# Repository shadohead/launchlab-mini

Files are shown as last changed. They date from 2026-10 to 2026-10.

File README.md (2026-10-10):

# LaunchLab Mini for Beyblade X

**A removable launch-practice meter for Beyblade X string launchers.** LaunchLab Mini uses an optical sensor to measure the launcher's shaft speed, then shows your peak RPM, launch history, and a replay of the device's tilt and rotation on an M5StickS3 screen. Use it to compare pulls, track consistency across practice sessions, and try to repeat a chosen launch.

Built around **M5StickS3 K150**, with separate printed mounts for the **small analog QRE1113** or **older TCRT5000 / LM393** sensor. The current firmware supports both sensors through a saved Sensor profile setting; the old TCRT 0.2.0 build is preserved separately. The M5 keeps its factory case, display, controller and battery; you do not need a phone to view your results. The mount is designed to be removable. Check the supplied launcher interface and printed fit before using it on your launcher.

**[USB firmware updater](https://shadohead.github.io/launchlab-mini/) · [Recovery & M5Stack reinstall](docs/RECOVERY.md) · [Firmware & print releases](https://github.com/shadohead/launchlab-mini/releases) · [Parts list & Amazon links](#parts-list--build-your-own) · [Build & wiring](docs/BUILD.md)**

**Prototype validation:** **0.11.1** is the user-checked prototype revision. It adds saved themes (Classic, Mint, Amber, Violet), a personal-best effect on the recap, and USB backup and restore of history, personal bests, appearance and settings (`K` export, `R` restore). It fixes 0.11.0, which restarted about once a second after boot (a loop-task stack overflow) and was withdrawn. One firmware still serves both sensors through the saved **Sensor profile** setting (QRE / Standard with an 80-count mark floor, TCRT5000 with 60). It was installed app-only on the owner's M5StickS3 K150: no restarts in a 120 s soak, history kept, a backup and restore round trip identical, and the screen, themes and pulls confirmed. The detector, sampling, thresholds and saved history format are unchanged from 0.10.22, which keeps measuring pulls that start right after an automatic save. Battery endurance, long-session reliability, absolute RPM/angle calibration, physical browser transfer and first install/rollback, and stock recovery remain separate checks.

## Sidecar form factor

**Sidecar** is the LaunchLab form factor with the M5StickS3 mounted on its own carrier beside a separate optical sensor attachment. Sidecar supports either QRE1113 or TCRT5000; the name describes the mounting layout, not the sensor, firmware or hardware revision.

See the [Sidecar build guide](docs/BUILD.md) and [hardware downloads](docs/HARDWARE_VERSIONS.md#current-downloads).

## Parts list — build your own

Start with **one M5StickS3 K150 + one analog sensor + three short wires + printed mounts and M2 screws**. The StickS3 already contains the display, processor, IMU and battery. Choose **QRE1113** for the current firmware/UI, or **TCRT5000 / LM393** for the preserved old-sensor firmware.

**Amazon affiliate disclosure:** As an Amazon Associate I earn from qualifying purchases. Amazon links below use the [Beywatch](https://beywatch.gg/) affiliate tag and help support the project at no extra cost to you.

| Qty per build | Part | Which build / purchase notes | Buy |
| --- | --- | --- | --- |
| 1 | **M5StickS3 K150** | Both sensor builds. ESP32-S3, 8 MB flash/PSRAM, intact factory case. | [Amazon — M5Stack Official, ordered](https://www.amazon.com/dp/B0GWHN8HK3?tag=beywatchgg-20) · [M5Stack K150 specs](https://docs.m5stack.com/en/core/StickS3) |
| 1 | **SparkFun QRE1113 analog breakout, ROB-09453** | Small-sensor build; exact ordered listing. **Analog ROB-09453** is required. Use the SparkFun link if Amazon is unavailable. | [Amazon — SparkFun analog board](https://www.amazon.com/dp/B07YM4551X?tag=beywatchgg-20) · [SparkFun](https://www.sparkfun.com/sparkfun-line-sensor-breakout-qre1113-analog.html) |
| 1, instead of QRE | **TCRT5000 / LM393 module with AO** | Old-sensor build. Choose the four-pin **VCC/GND/D0/A0** module and use A0. The mount uses the measured 31×13×1 mm PCB; check your board/header dimensions. | [Amazon — HiLetgo 10-pack, ordered](https://www.amazon.com/dp/B00LZV1V10?tag=beywatchgg-20) |
| 3 leads | **Short 2.54 mm jumper wires** | VCC, GND and AO/OUT; the ordered SinLoon pack is 8 cm male-to-female. Trim/reroute as needed, checking connector clearance. | [Amazon — SinLoon 8 cm](https://www.amazon.com/dp/B08M3QLL3Q?tag=beywatchgg-20) · [Amazon — ELEGOO mixed jumper kit](https://www.amazon.com/dp/B01EV70C78?tag=beywatchgg-20) |
| 1 | **USB-C data cable** | Flashing and charging; use an existing cable that carries data. | Use an existing data cable, or [Amazon search — USB-C data cable](https://www.amazon.com/s?k=USB-C+data+cable&tag=beywatchgg-20) |
| 1 set | **Printed M5 + sensor mounts** | QRE: six-piece v0.40 plate. TCRT: six v0.43 sensor pieces + a separate M5 carrier. v0.68 M5 with wire channel and shortened hook is the preferred separate carrier. | [Print files](docs/HARDWARE_VERSIONS.md#current-downloads) |
| See below | **M2 machine screws** | Head style and length depend on the mount revision. | [Amazon — ordered MEIYYJ countersunk assortment](https://www.amazon.com/dp/B07HC3LQYS?tag=beywatchgg-20); pan-head sizes below |
| Small amount | **1.75 mm PLA filament** | Print yourself or use a printing service; saved profiles target P1S / 0.4 mm nozzle. | Use existing PLA, a printing service, or [Amazon search — PLA filament](https://www.amazon.com/s?k=1.75mm+PLA+filament&tag=beywatchgg-20) |

Links marked **ordered**, plus the SparkFun, SinLoon, ELEGOO and uxcell links, match the project-related product listings from purchase history. Cable, filament and pan-head links marked **Amazon search** are general supplies, not exact ordered products. Check the selected variant and pack contents; purchasing a component does not establish printed fit.

### Screws, connectors and tools

The ordered MEIYYJ assortment includes M2×4/5/6/8 **flat/countersunk heads**. Its M2×5 pieces can supply the clip/crossbar screws, subject to head-seat fit. Obtain the **pan-head** pieces separately: [Amazon search — M2×4 pan-head](https://www.amazon.com/s?k=M2x4+pan+head+machine+screws&tag=beywatchgg-20) · [Amazon search — M2×6 pan-head](https://www.amazon.com/s?k=M2x6+pan+head+machine+screws&tag=beywatchgg-20).

| Assembly | Screws required |
| --- | --- |
| Original v0.40 M5 carrier | 2 × **M2×6 pan-head**, from below into the StickS3 mounts. |
| QRE v0.40 plate sensor assembly | 2 × **M2×5 countersunk** for the latch crossbar + 2 × **M2×4 pan-head** for the sensor pressure plate. |
| TCRT v0.43 sensor assembly | 2 × **M2×5 countersunk** for the separate clip caps + 2 × **M2×4 pan-head** for the sensor keeper; M5 fasteners are additional. |
| Preferred v0.68 M5 carrier | 2 × M2 screws; M2×6 is the nominal reference. **Actual length, insert engagement and seating remain unverified.** |

If your sensor has bare pads, add a **3-pin 2.54 mm header** or solder the three wires directly. The ordered [uxcell right-angle male header strip](https://www.amazon.com/dp/B01461DQ6S?tag=beywatchgg-20) can be cut to three pins; check header direction and cable clearance against the printed seat. You will also need a small screwdriver, cutters, and a soldering iron/solder if attaching bare wires or headers.

Use a **Beyblade X string launcher with the supplied removable clip/port interface**. The interface derives from Migbello's BP Gear Port Connector; check retention and optical access on your actual launcher before a pull. No universal launcher-fit claim is made by these CAD files.

Wire **AO/OUT → G1 / GPIO1**, **VCC → 3V3 / 3V3_L2**, **GND → GND**. DO is unused. The Grove red lead supplies 5 V; use the Hat 3.3 V pin for these builds. [QRE build/wiring](docs/BUILD.md) · [TCRT build/wiring](docs/TCRT5000.md) · [Sensor and hardware versions](docs/HARDWARE_VERSIONS.md).

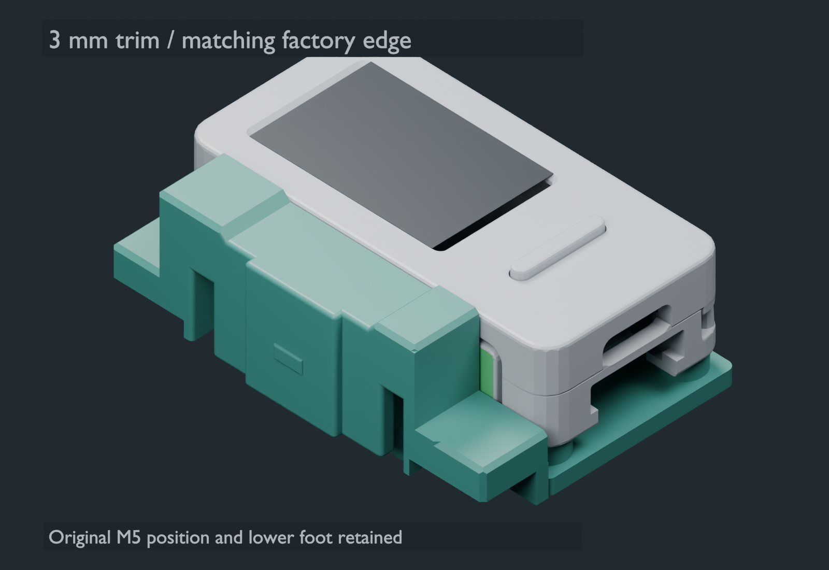
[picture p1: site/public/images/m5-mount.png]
LaunchLab Mini M5StickS3 mount, rendered from the published CAD


The updater defaults to **0.11.2**. It checks the complete known installed application before an app-only update, blocks downgrades and unknown/incomplete images, and skips writing an identical version. **Repair / rollback** requires an explicit target/backup confirmation; both app-only paths require the matching partition layout and boot selection. All modes check the detected ESP32-S3 chip and 8 MB flash capacity. The previous 0.11.1, 0.10.22, 0.10.21, 0.10.14, 0.10.11, 0.10.7 and 0.10.1 binaries are preserved. Physical browser transfer, four-image installation of this revision, stock recovery and rollback remain unverified. [Update details](docs/UPDATER.md) · [Recovery and vendor reinstall](docs/RECOVERY.md).

Current firmware: **0.11.2** (QRE1113 or TCRT5000 via Sensor profile). Old TCRT firmware: **0.2.0**. Preferred separate M5 carrier: **v0.68**; latest TCRT mount: **v0.43**. The original QRE **v0.40** complete plate is still available. Firmware, M5 carrier and sensor-mount versions are independent.

**[Choose your sensor and see every revision](docs/HARDWARE_VERSIONS.md)** — includes the preferred v0.68 M5 carrier, earlier v0.41–v0.50 models, historical v0.19 TCRT, and current QRE files.

## What it does

The current revision is **0.11.2**, running at 80 MHz with unchanged 50 kS/s optical sampling. It adds saved themes, a personal-best recap effect and USB backup/restore (`K`/`R`), and its build fails if any stack frame exceeds its budget. A saved Sensor profile selects QRE / Standard (80-count mark floor) or TCRT5000 (60-count floor). Controls are simpler: A opens or applies, B advances, hold B goes back or cancels. A saved 180-degree display flip and previewed brightness live in Settings. IMU startup recovery, prompt recaps, power diagnostics, tournament mode and USB keep-awake are retained; battery savings remain unmeasured. The old TCRT 0.2.0 release is an earlier RPM acquisition build with its own detector thresholds.

| Feature | What you see or do |
| --- | --- |
| Optical peak RPM | Three-turn elapsed-time average peak by default; validated single-turn peak is selectable in Settings. Three consistent turns confirm the pull before a peak is recorded. |
| Live level | Use the bubble and tilt angle while holding still to check the device's orientation before launching. |
| Launch recap | After a pull, see peak RPM, a clearer Start-to-End rotation replay, and frozen Start/End tilt circles. Press A to recall the latest recap. |
| Launch history | Review recent pulls and the current session's pull count, average, and best RPM. Retains up to 128 launches and 24 sessions on the device. |
| Pull and session trends | Compare individual pulls, a trailing five-pull average, and session averages to follow your practice consistency. |
| Tournament mode | Hold A on main to enter or exit; B cycles Recording Only/RPM. |
| Battery and auto-off | Check percentage, voltage and charging status. Shake-to-wake sleep after a configurable 1–10 minutes (3-minute default) without activity; a detected USB computer keeps it awake. |
| Browser firmware updates | Install over USB in desktop Chrome or Edge. Updates write only the application after checking the partition layout. |

RPM is **launcher-shaft speed**, not a direct measurement of the Beyblade's release RPM or its spin in the stadium. Motion replay shows rotation and gravity-relative tilt; it does not measure travel distance or absolute compass heading. The live level references the screen plane until the mounting orientation is calibrated.

## Device UI

These are saved device-framebuffer screenshots, not concept UI. Screens marked **DEMO** use synthetic sample data. The live/recap images are from firmware 0.6.2, and are historical examples; 0.10.1 has a revised tilt recap; history/trend images are from the 0.3.0 baseline and battery from 0.3.1. [Image provenance](docs/assets/ui/provenance.json) records their sources.

<table>
<tr><th>Live RPM & level</th><th>Launch recap</th><th>Launch history</th></tr>
<tr>
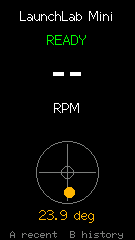
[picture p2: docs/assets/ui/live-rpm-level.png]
Idle live screen showing READY, RPM placeholder and bubble level
<td align="center"></td>
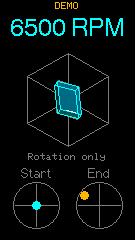
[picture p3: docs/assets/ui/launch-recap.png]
Demo launch recap showing 6500 RPM, a rotation replay and frozen start/end tilt circles
<td align="center"></td>
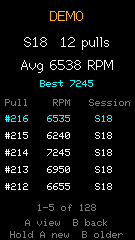
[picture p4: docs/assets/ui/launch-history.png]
Demo launch history listing pull RPM with session count, mean and best
<td align="center"></td>
</tr>
<tr><td>Ready state, held RPM result and level.</td><td>Recall the latest pull with A.</td><td>Browse pulls and session summaries.</td></tr>
</table>

<table>
<tr><th>Pull trend</th><th>Session trend</th><th>Battery</th></tr>
<tr>
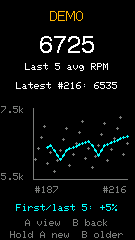
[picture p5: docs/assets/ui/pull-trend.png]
Demo pull trend with individual measurements and a five-pull average
<td align="center"></td>
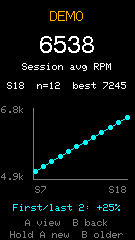
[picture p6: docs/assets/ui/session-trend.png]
Demo session trend plotting session-average RPM
<td align="center"></td>
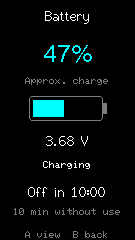
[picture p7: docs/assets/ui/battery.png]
Battery page showing approximate charge, voltage, charging state and auto-off countdown
<td align="center"></td>
</tr>
<tr><td>See variation across recent pulls.</td><td>Compare averages across sessions.</td><td>Check power before practice.</td></tr>
</table>

From the live screen, **A shows the last recap** and **B opens the menu** (History, New session, Battery, Settings, Tournament). In menus, A opens or applies, B moves to the next choice and hold B goes back one level or cancels an edit. Settings holds Sleep after, RPM method, Brightness, Flip display and Sensor profile; brightness and flip preview before you apply them. Hold A on main for one second to enter tournament mode (B cycles Recording Only/RPM; hold A exits). See the [firmware guide](firmware/LaunchLabMini/README.md).

## Exploded assemblies

The **Sidecar form factor** has **two independent assemblies**: the M5 display mount and your chosen optical sensor attachment (QRE1113 or TCRT5000). The views below use the exact published CAD meshes, separated for illustration. They do not assert a measured combined mounting position on a complete launcher. Electronics and screws are reference envelopes, not printed parts.

### Preferred M5StickS3 carrier — v0.68

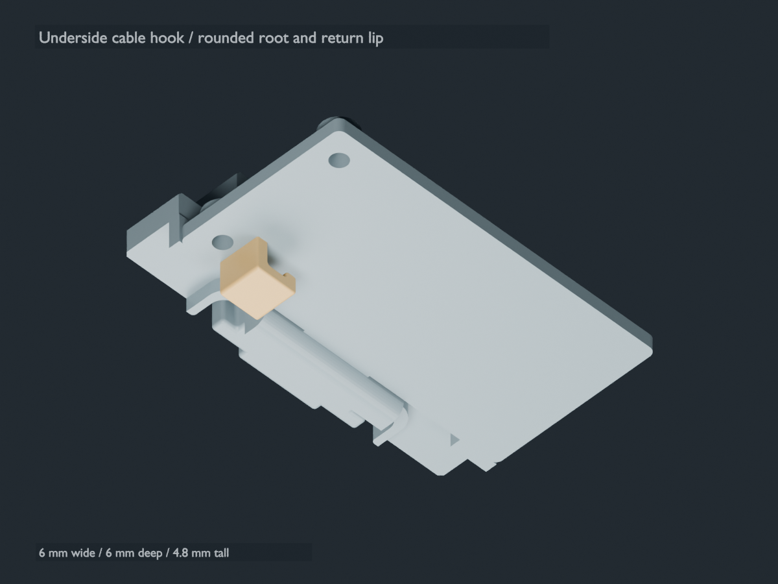
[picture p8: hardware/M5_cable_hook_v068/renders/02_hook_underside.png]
Preferred v0.68 M5 carrier with underside cable hook


One replacement carrier retains the two older support humps and adds the side-open
wire channel plus a **6 mm long, 4.8 mm tall underside hook**, opening downward in
the bottom-face preview. The hook is 2 mm shorter than v0.66. The sensor mount
remains separate. [P1S PLA 3MF](hardware/M5_cable_hook_v068/bambu/LaunchLab_v068_P1S_PLA_M5_ATTACHMENT_PROTOTYPE.3mf)
· [Complete package](hardware/M5_cable_hook_v068_package.zip)
· [STL, editable CAD and rebuild source](hardware/M5_cable_hook_v068/README.md).
Saved slice: **43m33s / 8.38 g PLA**. Physical seating, screw engagement, hook
strength and cable retention remain unverified. Stagger the three leads inside
the smaller hook and keep plug housings outside its opening.

### Earlier M5StickS3 carrier — v0.50

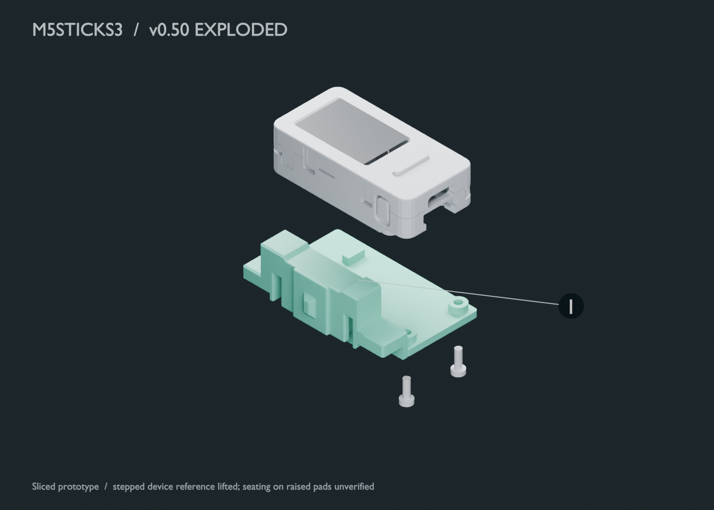
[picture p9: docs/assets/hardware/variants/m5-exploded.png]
Exploded earlier M5 v0.50 carrier, intact device reference and underside screws


**1 — Earlier equal-height M5 carrier:** one replacement printed piece with the v0.49 soft center ramp, recessed screw heads and supports raised to 2.3 mm. [Download v0.50 3MF](hardware/M5_equal_supports_v050/bambu/LaunchLab_v050_P1S_PLA_M5_EQUAL_SUPPORTS_TREE_SLIM.3mf) · [Full package](hardware/M5_equal_supports_v050_package.zip). Saved slice: 43m18s / 9.24 g PLA.

**Prototype: physical seating and leveling are unverified.** The original nominal M5 reference overlaps the taller pads in its saved assembly pose; it is lifted here for illustration. Screw length and insert engagement must be checked after the counterbore revision. STEP files contain only the added supports; the full carrier is mesh geometry.

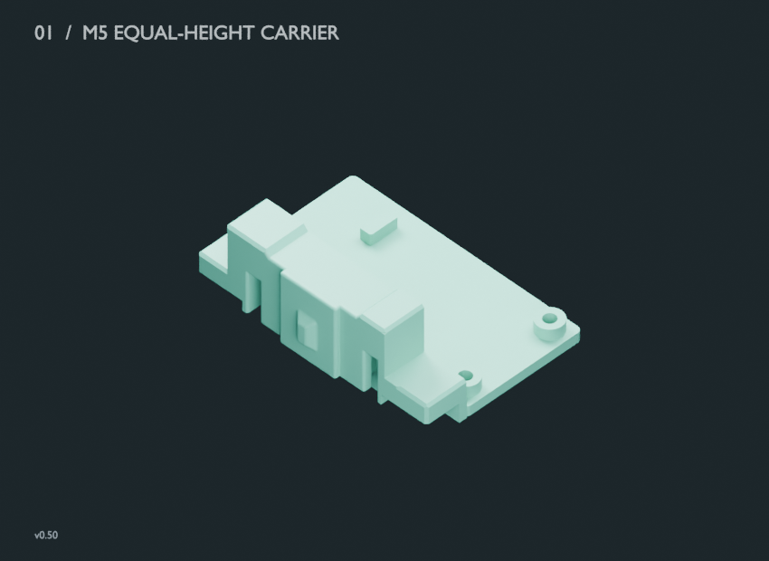
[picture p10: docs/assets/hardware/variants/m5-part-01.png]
Actual v0.50 printed M5 equal-height support carrier


### Earlier M5StickS3 display mount — v0.40

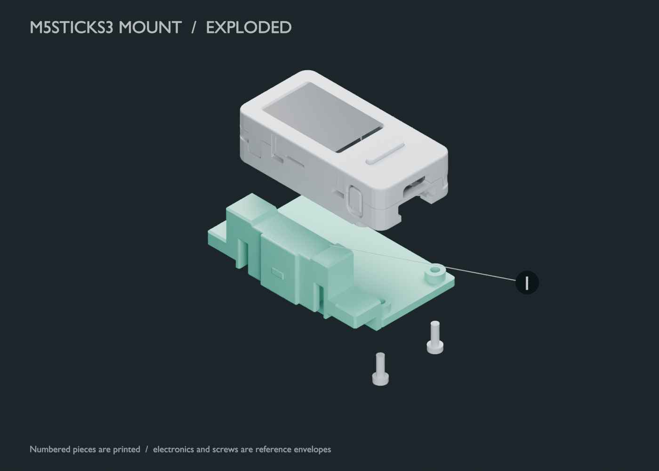
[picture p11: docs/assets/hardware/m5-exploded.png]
Exploded M5StickS3 assembly showing printed part 1, the intact M5StickS3 and underside screws


**1 — M5 platform:** supports the intact M5StickS3. Two M2×6 screws install from underneath into the device's existing mounts. The factory device, screen and soft-liner references are lifted for visibility in this view.

### Small QRE1113 sensor attachment

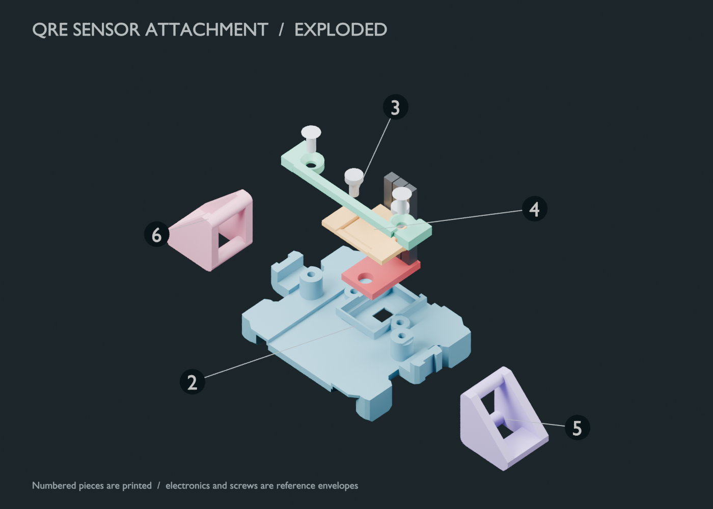
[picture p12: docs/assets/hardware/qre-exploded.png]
Exploded QRE1113 assembly showing the sensor base, latch crossbar, pressure plate, both launcher latches, sensor and fasteners


| No. | Printed piece | Purpose | Fasteners |
| --- | --- | --- | --- |
| 2 | QRE sensor base | Locates the small analog board and retains the launcher-facing interface. | Receives the crossbar and pressure-plate screws. |
| 3 | Latch crossbar | Retains the launcher latch assembly. | 2 × M2×5 countersunk. |
| 4 | Sensor pressure plate | Holds the QRE board against its seat. | 2 × M2×4 pan-head. |
| 5 | Left launcher latch | One side of the removable launcher attachment. | Retained by the base/crossbar assembly. |
| 6 | Right launcher latch | Opposite side of the removable launcher attachment. | Retained by the base/crossbar assembly. |

### Old TCRT5000 sensor attachment — v0.43

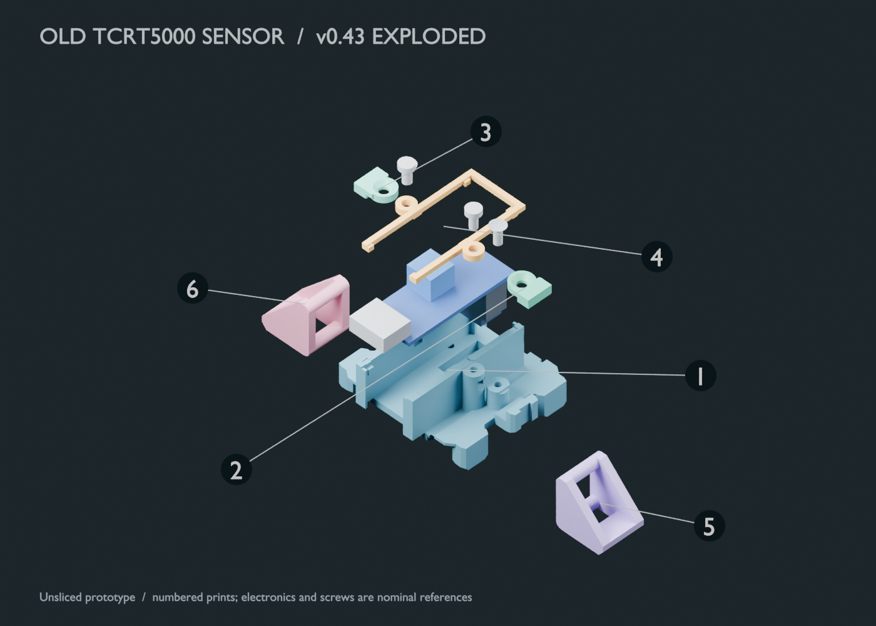
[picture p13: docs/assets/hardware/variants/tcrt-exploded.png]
Exploded TCRT5000 v0.43 mount with six printed pieces, analog sensor and nominal screws


This version uses the **older 31×13×1 mm TCRT5000 / LM393 PCB**. Two independent screw-on clip caps replace the earlier crossbar; M5 stays on a separate carrier. [Six-piece CAD/STL/STEP package](hardware/minimal_TCRT_split_keepers_v043_package.zip) · [Old-sensor wiring & firmware](docs/TCRT5000.md). This is an **unsliced CAD prototype**; fit, solder clearance, preload and optical alignment still need checking.

| No. | Printed piece | Purpose |
| --- | --- | --- |
| 1 | TCRT sensor cradle | Locates the larger board and preserves the launcher interface. |
| 2 | Left clip cap | Retains one launcher latch with an M2×5 countersunk screw. |
| 3 | Right clip cap | Retains the opposite latch with an M2×5 countersunk screw. |
| 4 | Sensor pressure keeper | Holds the board with two M2×4 pan-head screws. |
| 5 | Left launcher latch | Removable launcher attachment. |
| 6 | Right launcher latch | Opposite side of the launcher attachment. |

<table>
<tr><th>1 · TCRT cradle</th><th>2 · Left cap</th><th>3 · Right cap</th></tr>
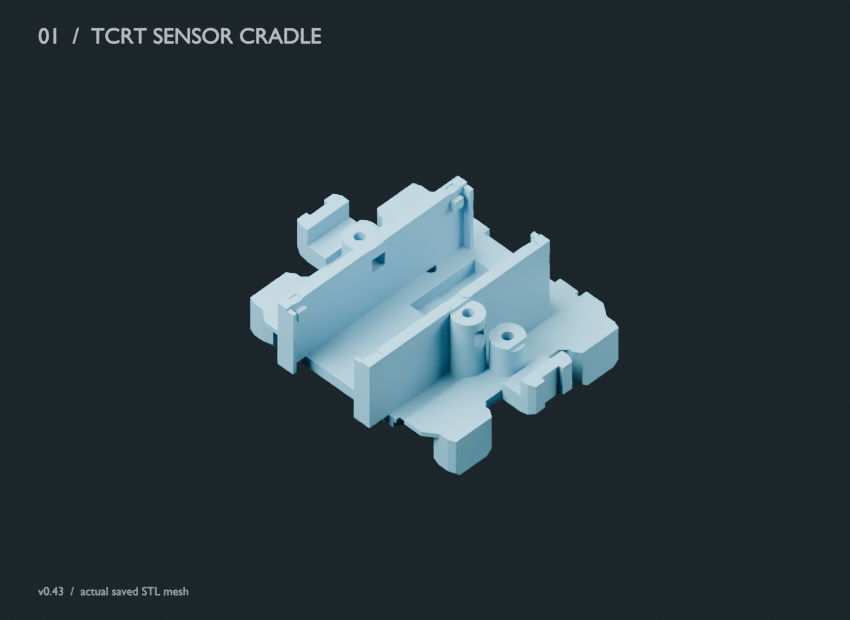
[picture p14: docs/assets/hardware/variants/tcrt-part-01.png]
TCRT sensor cradle
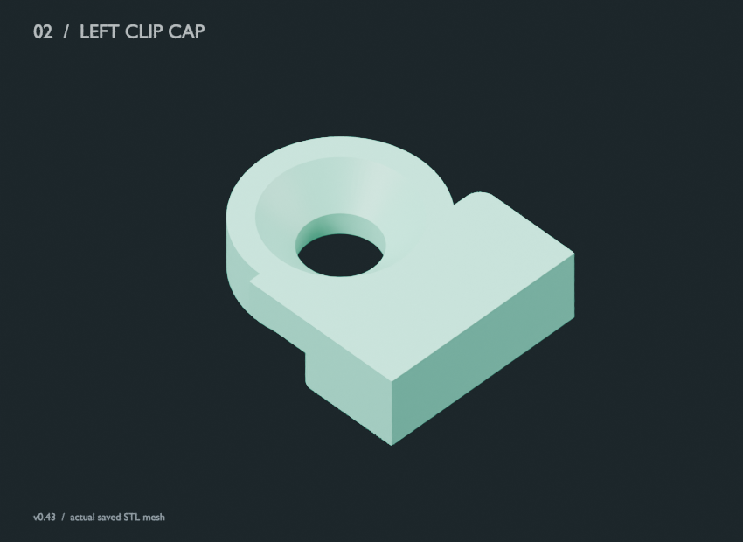
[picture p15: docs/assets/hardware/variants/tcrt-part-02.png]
Left TCRT clip cap
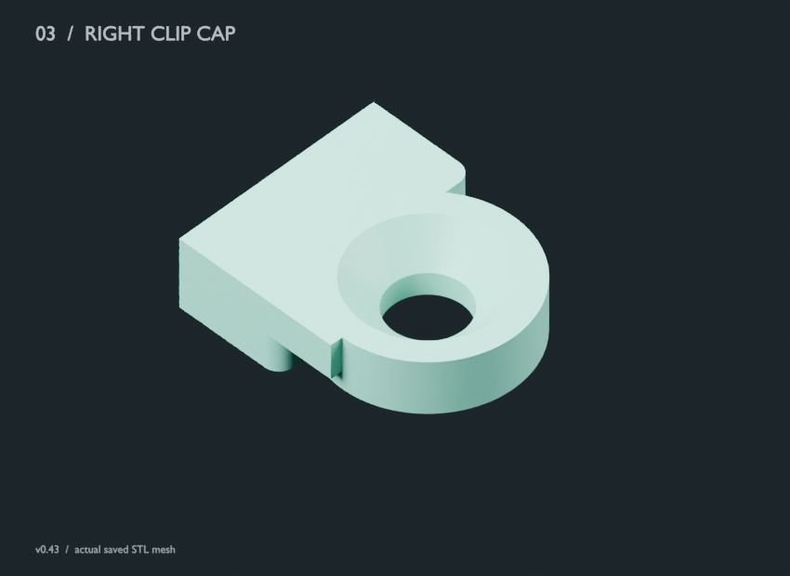
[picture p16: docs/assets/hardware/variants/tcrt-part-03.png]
Right TCRT clip cap
<tr><td></td><td></td><td></td></tr>
<tr><th>4 · Pressure keeper</th><th>5 · Left latch</th><th>6 · Right latch</th></tr>
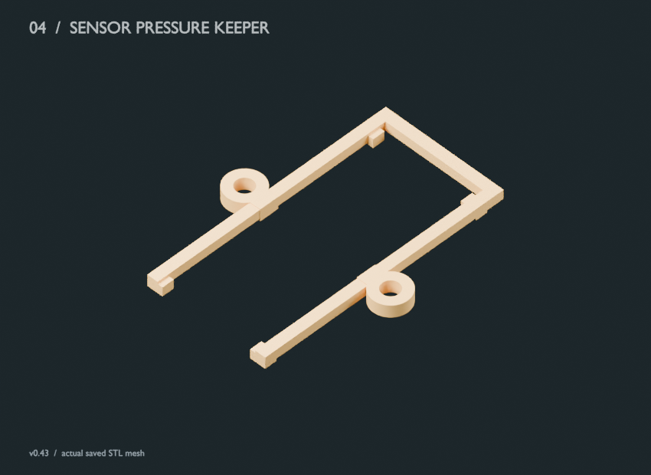
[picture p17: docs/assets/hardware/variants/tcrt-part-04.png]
TCRT pressure keeper
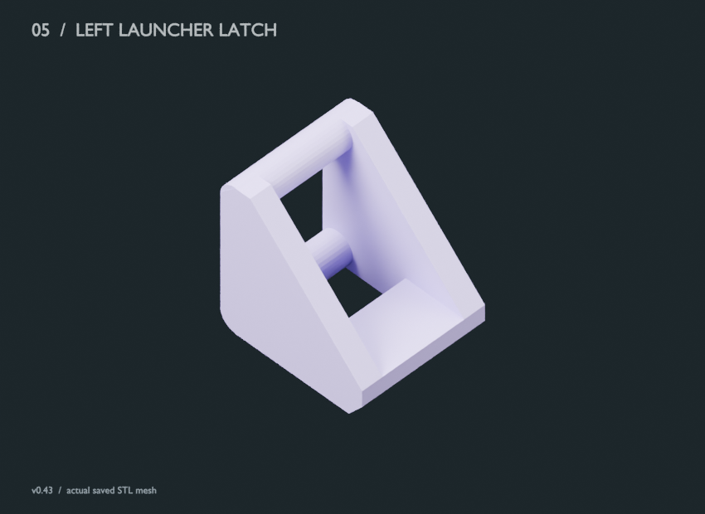
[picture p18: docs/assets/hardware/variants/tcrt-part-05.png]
Left TCRT launcher latch
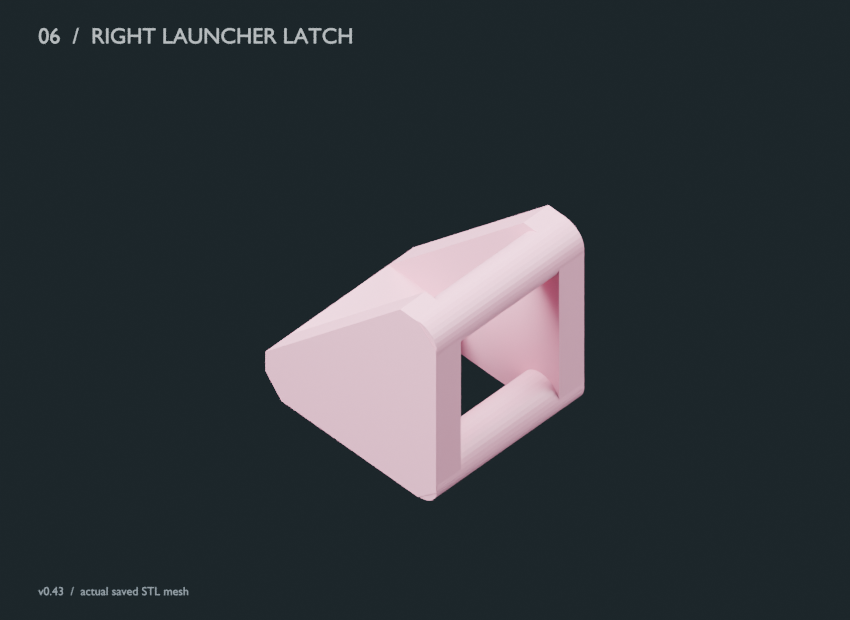
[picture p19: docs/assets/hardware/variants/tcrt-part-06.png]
Right TCRT launcher latch
<tr><td></td><td></td><td></td></tr>
</table>

### Each original QRE printed piece — v0.40 plate

All six pieces are included in the complete v0.40 plate. The views below show their actual mesh geometry; each build uses one of each.

<table>
<tr><th>1 · M5 platform</th><th>2 · QRE sensor base</th><th>3 · Latch crossbar</th></tr>
<tr>
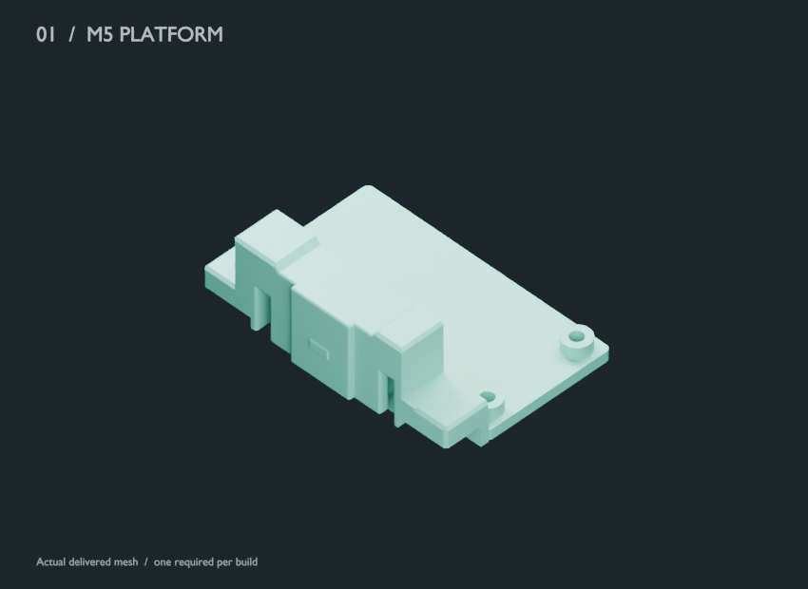
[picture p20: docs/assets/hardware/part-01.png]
Individual M5StickS3 stepped mounting platform
<td></td>
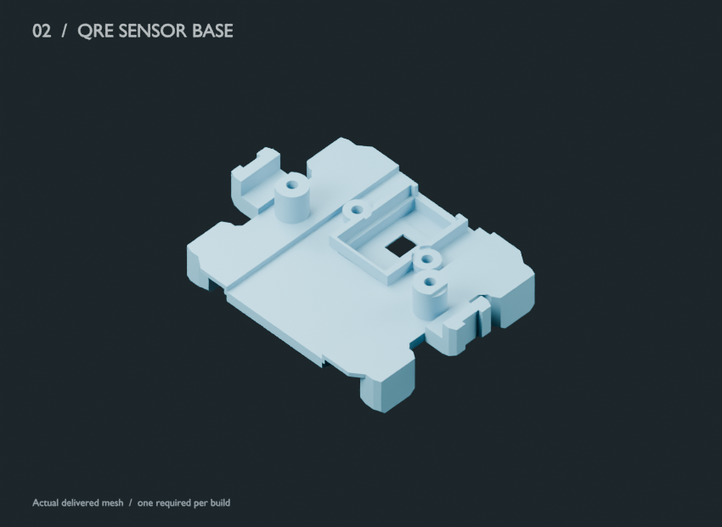
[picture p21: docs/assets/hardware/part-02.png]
Individual QRE1113 sensor base
<td></td>
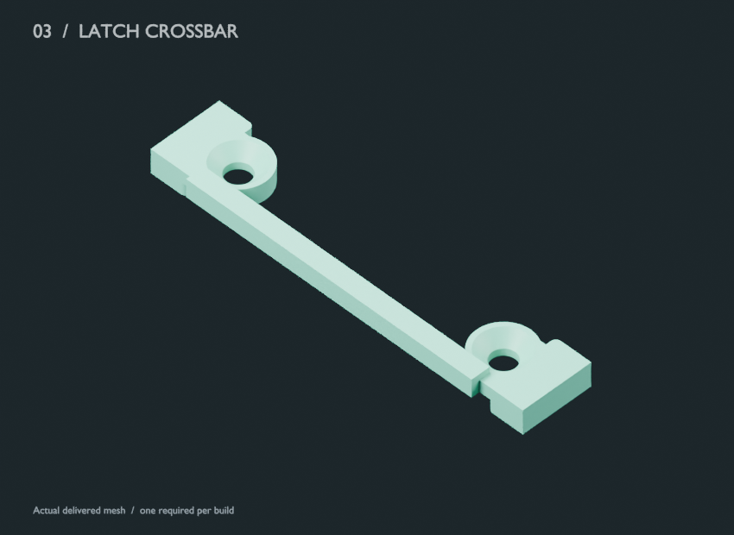
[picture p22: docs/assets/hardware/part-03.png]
Individual printed latch crossbar
<td></td>
</tr>
<tr><th>4 · Pressure plate</th><th>5 · Left launcher latch</th><th>6 · Right launcher latch</th></tr>
<tr>
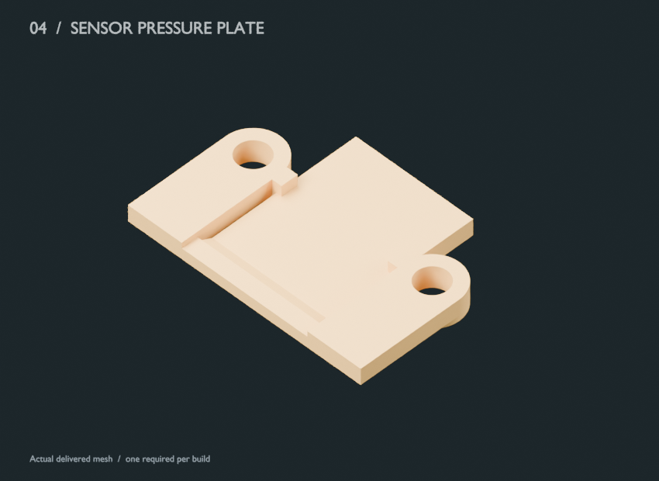
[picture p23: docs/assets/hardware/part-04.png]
Individual QRE1113 sensor pressure plate
<td></td>
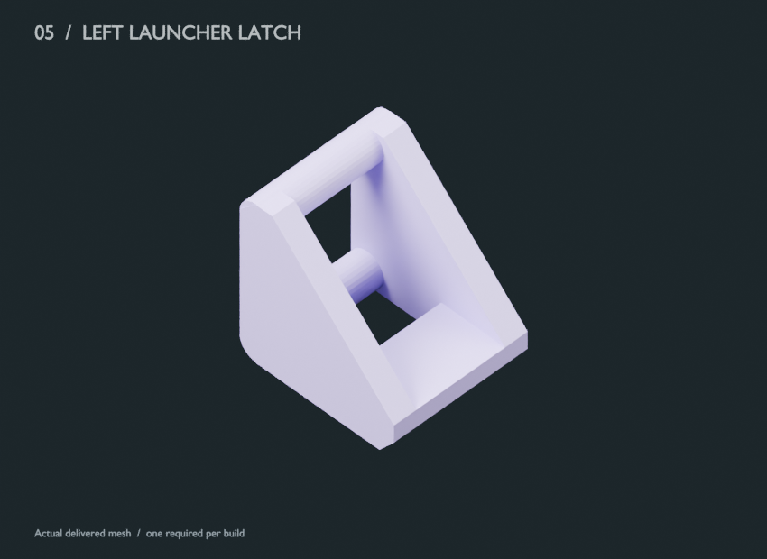
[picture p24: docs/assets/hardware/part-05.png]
Individual left launcher latch
<td></td>
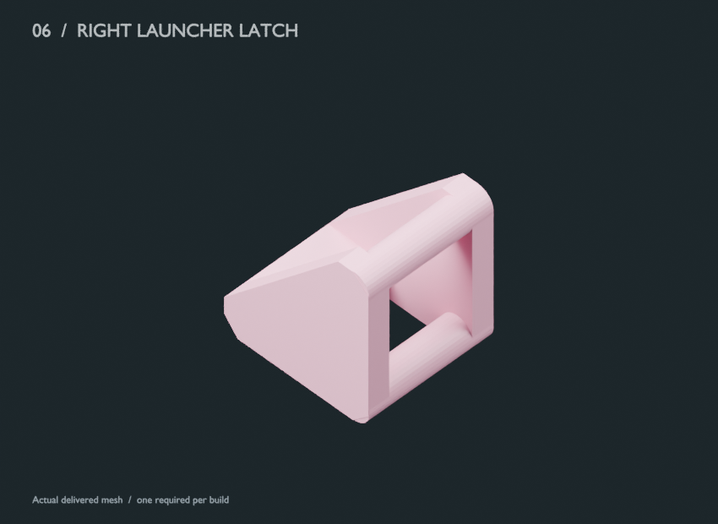
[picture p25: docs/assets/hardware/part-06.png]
Individual right launcher latch
<td></td>
</tr>
</table>

If your five-piece sensor attachment is already built, only the **v0.40 M5 platform** needs replacement. [Download the combined 3MF](hardware/LaunchLab_v040_ALL_ITEMS_PRINT/bambu/LaunchLab_v040_P1S_PLA_ALL_ITEMS_ONE_PLATE.3mf) or the [full print package](hardware/LaunchLab_v040_ALL_ITEMS_PRINT_package.zip). Physical fit, button/thumb access and launch-load retention still need checking after printing. [Render provenance](docs/assets/hardware/provenance.json) identifies the source meshes; `scripts/render-readme-hardware.py` reproduces these illustrations in Blender.

[Latest-render provenance](docs/assets/hardware/variants/provenance.json) records the frozen source mesh hashes; `scripts/render-variant-hardware.py` reproduces the new illustrations. [Version history](docs/HARDWARE_VERSIONS.md) explains v0.68 and every earlier v0.41–v0.50 change.

## Get started

Choose **QRE1113 or old TCRT5000** in the [version guide](docs/HARDWARE_VERSIONS.md) first. For TCRT use [its build/restore guide](docs/TCRT5000.md); the following complete-plate/updater steps are for QRE.

1. Download the [complete v0.40 print package](hardware/LaunchLab_v040_ALL_ITEMS_PRINT_package.zip) or open [the combined 3MF](hardware/LaunchLab_v040_ALL_ITEMS_PRINT/bambu/LaunchLab_v040_P1S_PLA_ALL_ITEMS_ONE_PLATE.3mf) in Bambu Studio.
2. Assemble with an intact M5StickS3 K150 and analog QRE1113. Read [BUILD.md](docs/BUILD.md) for wiring, fasteners and print settings.
3. Open the [updater](https://shadohead.github.io/launchlab-mini/) in desktop Chrome or Edge, choose Update or First install, connect USB with the M5 powered on, and select the device. The updater attempts download mode automatically; follow its manual reset steps if connection fails.

Update writes only the application at `0x10000` after checking the installed partition table. First install replaces the factory firmware and partition table and requires an explicit checkbox. Neither flow erases all flash. Every downloaded image is SHA-256 checked and writes use esptool's device MD5 verification. Chip identity alone cannot distinguish every ESP32-S3 board, so confirm your device is specifically an M5StickS3 K150.

## Hardware files

- [All hardware revisions and sensor compatibility](docs/HARDWARE_VERSIONS.md), with a [checksum inventory](hardware/versions.json).
- [Preferred v0.68 M5 carrier](hardware/M5_cable_hook_v068/): side-open wire channel, two support humps and shortened underside cable hook; CAD, source and saved P1S PLA slice.
- [Earlier v0.50 M5 carrier](hardware/M5_equal_supports_v050/): preserved sliced prototype, plus v0.44–v0.49 history.
- [v0.43 TCRT mount](hardware/minimal_TCRT_split_keepers_v043/): latest unsliced six-piece prototype, plus v0.19/v0.41/v0.42 history.

- [v0.40 complete plate](hardware/LaunchLab_v040_ALL_ITEMS_PRINT/): all six prints, source STLs, QRE STEP files, profiles and digital verification.
- [v0.40 M5 mount](hardware/LaunchLab_v040_right_block_print/): editable Blender mesh and GLB, independent 3MF, dimensions and CAD reports.
- [v0.33 QRE base](hardware/LaunchLab_v033_flush_QRE/): editable Blender and STEP assembly for the current sensor seat. Other sensor parts are frozen in the complete package.

The CAD includes original launcher attachment geometry derived from Migbello's BP Gear Port Connector. Preserve its attribution and share-alike notice when distributing changes.

## Develop

Install Arduino CLI, then run `bash scripts/build-firmware.sh`. It installs the pinned ESP32 3.3.0, M5Unified 0.2.23 and M5GFX 0.2.30 dependencies into a project-local cache and compiles the 8 MB flash / OPI PSRAM target. Source builds may differ byte-for-byte from the archived binary across hosts/toolchains. The published binary is the exact saved release, with recorded checksum.

Run `bash scripts/test-firmware.sh` for 20 native C++ suites with address/undefined sanitizers and six production harnesses. Website development requires Node 24+:

```sh
cd site
npm ci
npm test
npm run dev
npm run build
```

`python3 scripts/verify-artifacts.py` verifies published checksums and 3MF ZIP integrity. GitHub Actions runs the native tests, updater tests and artifact checks before deploying Pages from `main`.

19 frozen M5 firmware versions are in [firmware/releases](firmware/releases/catalog.json), including the working 0.3.0 QRE baseline and the separate 0.2.0 old TCRT5000 variant. Only current QRE firmware is offered by the web updater. Historical source snapshots retain their original layouts and notes; use each release's source rather than mixing headers across versions. Device backups, personal practice exports and factory flash dumps are excluded.

## Validation scope

The current firmware passed native tests and 13 saved optical waveform replays, and was installed with a verified flash hash. A prior QRE baseline was reported to work well in live use. Fresh physical acceptance of the single-turn peak algorithm, independent absolute RPM calibration, and printed v0.40 fit/strength remain pending. Browser flashing is covered by mocked-loader tests and browser UI checks; a physical browser-flash trial is still required.

RPM measures launcher-shaft revolutions, not direct Beyblade release RPM. Tilt replay has no measured travel distance or compass heading. Digital CAD/slicing checks establish file consistency, not printed fit or safe launch-load retention.

Software: MIT with upstream component licenses. Hardware: preserved Creative Commons Attribution Share Alike notices. See [LICENSE](LICENSE) and [THIRD_PARTY_NOTICES.md](THIRD_PARTY_NOTICES.md).

Firmware 0.11.2 adds a same-page **High score effect** sample in Settings and its editor. The owner tested the local candidate successfully; the final versioned binary is software-validated and its physical device install is pending. [Release evidence](firmware/releases/0.11.2-sticks3-qre1113-scorepreview/README.md).

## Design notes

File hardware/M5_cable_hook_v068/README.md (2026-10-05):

# Preferred separate M5StickS3 carrier — v0.68

This is the preferred separate carrier, selected by the project owner. It combines
the side-open wire channel, two older rounded support humps and the shortened
underside cable hook. It is a replacement M5 carrier only; reuse your sensor mount.
The stacked M5-over-sensor prototype is a different assembly.

The hook is 6 mm long in the bottom-view preview, shortened 2 mm from v0.66 with
its root fixed. It is 6 mm wide, projects 4.8 mm below the plate, has 1.6 mm walls,
and opens toward image-down in that view. The nominal mouth gap is 2.2 mm; the
inside cavity is 2.8 × 3.2 mm. Three nominal 1.3 mm insulated leads fit in a
staggered two-row arrangement, loaded separately. Keep DuPont housings outside
the hook. Actual wire diameters and printed retention require a dry fit.

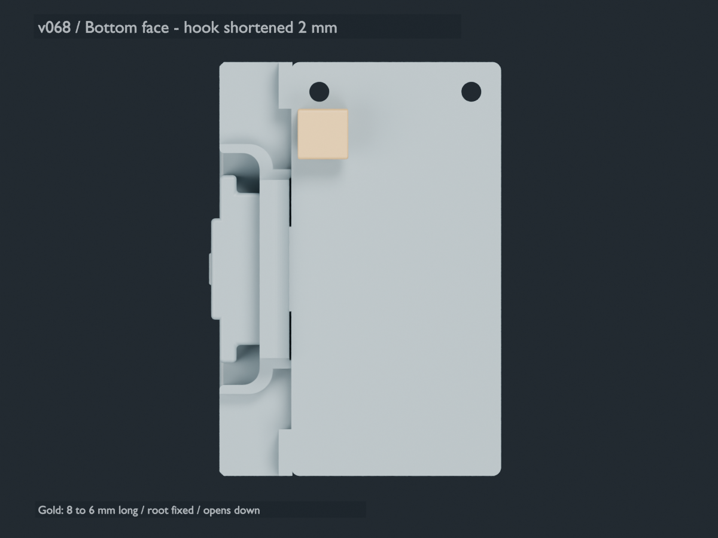
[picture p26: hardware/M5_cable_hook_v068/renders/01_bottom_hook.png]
Bottom face and shortened hook


## Print and assemble

- [Sliced P1S PLA project](bambu/LaunchLab_v068_P1S_PLA_M5_ATTACHMENT_PROTOTYPE.3mf)
- [Print-oriented complete carrier STL](stl/01_M5_channel_two_humps_cable_hook.stl)
- [Editable Blender model](LaunchLab_v068_M5_underside_cable_hook.blend)
- [Complete download package](../M5_cable_hook_v068_package.zip)
- [Standalone rebuild instructions](source/REBUILD.md)

Print one carrier using the saved -90° Y pose with the wire groove open upward.
Retain the WIRE GROOVE SUPPORT BLOCKER and Tree Slim supports. The saved P1S /
0.4 mm nozzle / PLA slice uses 0.2 mm layers and four walls, estimating **43m33s /
8.38 g** including supports. Re-slice and select the filament for your printer.
After cooling, remove accessible supports and inspect the hook mouth and groove.

With the M5 removed, lay all three leads into the side groove. It is 34 mm long,
3 mm high and at least 6.25 mm deep, with 1.5 mm retained walls. Connector housings
stay outside the groove ends. The hook provides a separate cable-management point.
Choose the shorter plug-in harness after a dry fit with relaxed bends.

The carrier retains two underside screw seats and a nominal pair of M2×6 screw
references. Confirm actual screw length and engagement in the factory M5 inserts.
Dry-fit the device on the two support humps; do not force it onto the pads or
tighten screws against rocking.

## Validation and limits

The complete carrier is one watertight mesh. CAD checks confirm retained prior
carrier material, nominal staggered-wire clearance and a clear wire groove.
The saved 3MF matches the manufacturing STL and its G-code checksum passes.
All 173 model layers have deposition, both support humps and the hook are present,
and no deposition enters the checked hook-opening or groove interior cores.
These are digital checks; physical seating, screw engagement, hook strength,
cable retention and launcher clearance remain unverified. No v0.68 print was sent.

The older nominal M5 underside overlaps the retained 2.3 mm support pads, as in
v0.65. Selection as the preferred design does not establish physical acceptance.
The factory M5 references are hidden in the primary Blender view for inspection.

The full carrier is mesh geometry. `step/CABLE_HOOK_ONLY.step` describes only the
analytic hook. `preview/` and `references/` are inspection geometry, not extra
parts to print. `source/carrier_before_hook.stl` preserves the exact v0.65 baseline;
`source/build.py` regenerates the hook union and print pose without private feedback.

Original BP Gear Port Connector: Migbello, Thingiverse 6856080. Attribution-Share
Alike notice, version unspecified, is preserved in [LICENSE.txt](LICENSE.txt).

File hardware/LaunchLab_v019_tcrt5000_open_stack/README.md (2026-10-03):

# LaunchLab v0.19 — compact OLD TCRT5000 + top-mounted M5StickS3

This is a **separate old-sensor variant**. The complete v0.17 QRE1113 package is preserved unchanged while you print it. The intact M5 sits exposed on top of a sensor cradle and removable top dock; there are no enclosing M5 walls, separate battery bay, screen cradle or top retaining frame.

The core footprint is **43.15 × 48 mm**, compared with the previous M5/TCRT enclosure's 44 × 72.5 mm. It is 24.5 mm shorter, a 34% reduction in length. Original clips extend the assembled width to approximately **59.78 mm**. The M5 top is Z38.9, **35.12 mm above the modeled launcher plane**; it is 2.7 mm below the earlier v0.15 frame top. Provisional connectors and the short rear loop extend length to about 56.2 mm; actual connector housings and bends are unmeasured.

## Sensor identity and dimension basis

**OLD means the blue TCRT5000/LM393 analog/digital module pictured in IMG_7445–7448. It does not mean QRE1113.** The source is the user's recorded caliper measurements, copied into `references/TCRT5000_user_measurements_2026-09-21.md`, together with three original photos.

| Feature | Dimension used | Evidence boundary |
|---|---|---|
| PCB | 31 × 13 × 1 mm | Recorded user measurement |
| PCB lower face to outer lens tips | 12 mm | Recorded user measurement; includes lens protrusion |
| Lens protrusion from housing | 2.5 mm | Already included in the 12 mm total |
| Optical housing footprint | 10 × 6 mm | User measurement; orientation follows prior CAD and photos, lateral center needs confirmation |
| Lens-pair envelope | 7 × 6 mm | User's 6 × 7 measurement oriented as prior CAD; not individual lens diameters |
| Adjustment block | 7 × 7 × 6 mm | Opposite face from optical head, confirmed in side photo |
| Bare header | 6 mm beyond PCB, 4 mm high | User measurement; lateral footprint follows prior CAD |
| Solder/component clearance | 2 mm on both faces | Locations unmeasured; four corner contact lands are reserved from photo-based assumptions |

The correct measured component thickness is **12 + 1 + 6 = 19 mm**. Earlier v0.15 CAD placed the PCB only 10.5 mm above the lens tips. This variant honors the recorded 12 mm rather than silently copying that smaller projection. PCB lower face is Z16.1, top Z17.1, lens tips Z4.1 and adjustment-block top Z23.1. The M5's lowest back is Z23.9, leaving **0.8 mm above the adjustment block**. Two 2 mm support beams run beside the components, with a 0.3 mm soft liner.

PCB pocket clearance is 0.3 mm per side. Four small underside corner lands support the board. The removable M5 top dock includes a 1.4 mm keeper that captures those corners with 0.2 mm nominal vertical play. Its four screws sit outside the M5 footprint and remain accessible. Thin holder cheeks are 1.3 mm thick; the native launcher attachment is kept at its original scale.

The upper optical recess in the printed port accommodates the 7 × 6 lens envelope. Native material below the modeled launcher plane and original clip mating regions are preserved. **The actual launcher is not modified or fully modeled.** Its reported 5–6 mm opening may obscure part of the optical path. Printed clearance does not prove black/white contrast, target alignment or launch-speed response.

## Complete first-build inventory

Print **five installed pieces**, one of each:

| Piece | Print file | Role |
|---|---|---|
| Old-sensor attachment port | `stl/01_TCRT_attachment_port.stl` | Native launcher connection and old-sensor upper optical recess |
| Sensor cradle | `stl/03_TCRT_sensor_cradle.stl` | PCB seats and original clip keepers |
| Removable M5 top dock | `stl/04_TCRT_M5_top_dock.stl` | M5 support and integrated PCB corner keeper |
| Left launcher mounting clip | `stl/02_latch_LEFT.stl` | Original-scale left clip, included unchanged |
| Right launcher mounting clip | `stl/02_latch_RIGHT.stl` | Original-scale right clip, included unchanged |

**`bambu/LaunchLab_v019_P1S_PLA_ALL_PARTS.3mf` is the complete five-piece first-build plate.** `LaunchLab_v019_ALL_PARTS_UNSLICED.3mf` is the same inventory as geometry only. The three-piece `REPLACEMENTS` plate is for an upgrade if the original clips are already owned; the clips-only plate is also included. Do not use a QRE dock or keeper in this old-sensor stack.

The complete five-piece P1S/PLA plate estimates **1h 27m 57s and 21.80 g**, including 11.20 g supports. The sensor-fit pair estimates 18m 21s and 2.83 g; the M5 mount sample estimates 9m 43s and 0.51 g. These are local slicer estimates, not completed prints.

Required nonprinted parts:

- One intact M5StickS3 K150 and one old blue TCRT5000/LM393 module.
- Four **M3×8 DIN912 socket-head screws** to join sensor cradle and port. Nominal printed-post engagement is 6.6 mm; tips remain 0.766 mm above the source post bottom.
- Two **M2×6 pan-head screws** into the user-confirmed brass M5 inserts, from underneath. Nominal insert engagement is 1.7 mm; actual insert depth must be checked.
- Four **M2×4 pan-head screws** for the removable M5 top dock, into printed pilots. Nominal engagement is 2.6 mm. These do not pass through PCB holes.
- A 0.3 mm soft liner cut to the two long M5 beams, and a short three-wire analog harness. Connector housings and strain relief are not physically measured.

No nuts, separate display, external battery or Grove attachment are required. Factory M5 cover screws stay installed. Existing analog wiring remains sensor VCC → Hat 3V3_L2, GND → Hat GND, AO → Hat G1. DO is unused. Verify actual labels and polarity; no firmware or device setting is changed by this package.

## Fit samples and assembly

Print the optional samples before committing to the dock:

- `extras/11_TCRT_SEAT_FIT.stl` and `extras/12_TCRT_KEEPER_FIT.stl`, used together: checks PCB size, corner lands, solder clearance, keeper play and printed pilots. The keeper must land on clear PCB corners, not components or solder joints. These locations are an assumption until checked against your board.
- `extras/13_M5_MOUNT_FIT.stl`: checks the two brass axes, 2 mm stepped factory mounting face, liner and M2 insertion depth. The two axes are 18 mm apart, 3 mm inward from the Grove-end edge.

1. Install both original clips in the separate old-sensor port. Lower the sensor cradle onto the port and fit four M3×8 screws. Confirm clip opening and retention on the actual launcher without forcing or scaling it.
2. With the M5 top dock removed, lower the old PCB vertically onto the cradle's four corner lands, lens tips downward and bare header toward +Y. Check underside solder, head clearance and clear PCB corner contact areas.
3. Prepare the M5 top dock separately. Add the 0.3 mm liner to its long beams and place the intact M5 on them, **Grove/USB toward −Y and Hat toward +Y**. Install two M2×6 screws from below into the brass inserts while this top module is off the cradle. Stop if a screw bottoms before seating. Grove carries no attachment load.
4. Lower this M5/top-dock module onto the sensor cradle. Its integrated corner keeper captures the PCB with 0.2 mm nominal play. Fit four M2×4 screws through the exposed side ears into the cradle's pilots. Check that the keeper avoids all solder/components, the adjustment block has its 0.8 mm clearance, and printed pilots hold without splitting. Do not bend or compress the PCB.
5. Connect the short three-wire analog harness at +Y, with both the sensor header and Hat at the same end. The open rear accommodates the socket and wire bends. Keep wires clear of screws, clip movement and the optical path. Screen, buttons, USB/Grove and Hat remain exposed.

For sensor service, unplug the harness and remove the four M2×4 top-dock screws. Lift the M5 and its top dock together, then lift the sensor vertically from the open cradle. To separate the M5 from its top dock, access the two underside M2×6 screws while that module is off the cradle. Four M3 screws release the cradle from the launcher port if required. No populated board needs to slide through fixed rails.

## Files and verification

`LaunchLab_v019_tcrt5000_open_stack.blend` contains assembled, underside, exploded and complete five-piece print views. `step/` contains editable solids, `stl/` contains print-oriented meshes, and `preview/` holds assembled meshes and reference envelopes. Reference electronics and screws are not printed pieces. `print_inventory.json` specifies quantities, hardware and filenames. `reports/` provides CAD/mesh validity, preserved interface checks, nominal clearances, mounting bearing/contact, driver access, sampled assembly/service/clip movement, saved-model and project readback, slice metrics and package completeness.

The original clips are unchanged from the older full v0.2 source. The manufacturer M5 reference uses the three assembled shell pieces with a rigid translation only. Pot/header/head registration and corner contact lands have documented assumptions; plug/wire/solder allowances are not scans of the populated assembly. Digital checks and local slice estimates do not establish physical fit, attachment strength, insert depth, optical performance, RPM accuracy or runtime. No printer job or purchase is initiated.

See `LICENSE.txt` for Migbello's original BP Gear Port Connector attribution. Manufacturer case geometry is an unmodified reference, not a printed replacement for the factory M5 shell.

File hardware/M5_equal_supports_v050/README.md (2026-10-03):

M5 equal-height supports v050

The two existing 6 x 2.6 mm support pads are raised from 0.5 to 2.3 mm above the deck, matching the existing screw standoffs at Z -3.5. Each gains 1.8 mm. Footprint, location and 0.5 mm corner radii are unchanged. All other v049 carrier geometry is preserved, including the softened center ramp, underside screw-head recesses and launcher receivers.

The nominal manufacturer M5 reference remains at its old pose for provenance. It has a stepped underside and overlaps the taller pads; it is not presented as a verified assembly. The requested equal-height support configuration requires physical seating and leveling inspection. The printable carrier is one watertight solid. STEP files contain only the added support geometry; the complete carrier is mesh geometry.

Print orientation: existing +90-degree Y side orientation. One replacement carrier, sensor mount separate.

Verified P1S PLA slice: 43m18s, 9.24 g total, about 2.33 g support including support transition. Tree auto with Tree Slim style. AMS A3 selected in Bambu Studio send dialog; job has not yet been dispatched at packaging. GUI slice estimate matches the local saved slice.

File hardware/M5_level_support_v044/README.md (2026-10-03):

M5 leveling supports v044

The accepted v040 trimmed carrier gains two integral 6 x 2.6 mm pads underneath the opposite end of the M5 flat back panel, just inboard of the Hat connector. Pads rise 0.5 mm above the deck to the factory back-plane datum Z -5.3. The front mounting faces are at Z -3.5 because the factory underside is stepped. These unequal pad heights match the different M5 contact surfaces and keep the modeled device level.

Existing two M2x6 underside screws, device pose, USB-C direction, 3 mm right-block trim, matching bevel and launcher receivers remain unchanged. No change to either sensor mount. Replacement: one printed carrier. Physical leveling, preload and fit still need a dry fit. The STL is unsliced.

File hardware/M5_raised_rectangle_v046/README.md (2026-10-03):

M5 raised center rectangle v046

The tiny rectangular feature on the launcher-facing plate extends outward an additional 1 mm: its projection increases from 0.25 to 1.25 mm. Its position and footprint stay the same, and its original rounded outer cap is copied intact. This follows the user clarification: Make it stick out farther.

The v045 underside screw-head recesses, M5 standoffs, opposite-end supports, right-block trim, and remaining launcher attachment geometry are preserved. Supply one replacement carrier. STL and generic 3MF use the existing side print orientation and are unsliced. The complete carrier is mesh geometry, editable in Blender; the STEP file describes only the newly added root. Section and original meshes are inspection references. No printer dispatch. Revised physical launcher contact and retention need a fit check.

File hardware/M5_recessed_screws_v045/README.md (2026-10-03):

M5 recessed screw heads v045

Two cylindrical recesses are cut into the underside of the existing v044 carrier: diameter 4.2 mm, depth 1.4 mm, centered on the existing M2 holes. Their flat shoulders seat the previous nominal 3.8 mm diameter x 1.4 mm thick screw heads flush with the deck underside. The existing 2.4 mm through holes and 5 mm diameter standoffs remain unchanged.

This advances each screw 1.4 mm and reduces the clamped material from 4.3 mm to 2.9 mm. A nominal 4 mm screw reaches 1.1 mm into the device, and a nominal 6 mm screw reaches 3.1 mm; usable insert depth and actual fastener dimensions have not been measured. The reference screws show the existing 6 mm example, not a new hardware selection.

The launcher attachment, device pose, right-block trim, rounded bevel, and opposite-end support pads (0.5 mm high) are preserved. No sensor mount change. The complete carrier is supplied as a mesh and editable Blender file; STEP files describe only the counterbore cutters. Section meshes and hardware are inspection references, not printable parts. Replacement STL is in its existing side print orientation and is unsliced. No printer dispatch.

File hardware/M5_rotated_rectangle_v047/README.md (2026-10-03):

M5 taller center rectangle v047

The raised center rectangle turns 90 degrees in the plane of the launcher-facing plate. Its root footprint changes from 3.75 x 1.75 mm to 1.75 x 3.75 mm. It grows 1 mm at each end in the short direction shown toward bottom-left and top-right in the preview. Its center and 1.25 mm outward projection stay the same. The actual v046 rectangle, including its rounded cap, is rotated intact.

One replacement carrier. STL and generic 3MF are unsliced and retain the existing side print orientation. The underlying plate, launcher receivers, M5 screw-head recesses, standoffs and supports are unchanged. The complete carrier is editable mesh geometry in Blender; STEP describes only the rotated analytic root. Reference meshes are not printable parts. Revised physical launcher contact and retention remain untested. No printer dispatch.

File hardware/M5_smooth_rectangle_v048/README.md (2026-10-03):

M5 smooth center tab v048

The center tab now has sloped trapezoidal sides and 0.3 mm fillets around its top, corners, and the concave junction with the plate. The nominal base is 2.75 x 4.75 mm and the nominal top before rounding is 1.75 x 3.75 mm. The rounded base blend extends slightly beyond the nominal base. Projection is still 1.25 mm, centered in the accepted direction.

One replacement carrier. Unsliced STL and generic 3MF use the existing side print orientation. Existing M5 mounting geometry, screw-head recesses and launcher receivers remain unchanged. Complete carrier geometry is an editable mesh in Blender; STEP describes only the analytic smoothed tab and a 0.01 mm root into the plate. Reference meshes are not printable parts. Revised launcher contact and retention require physical fit testing. No printer dispatch.

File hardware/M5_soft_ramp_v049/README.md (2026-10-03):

M5 softer center ramp v049

The center tab uses a broader nominal 4.25 x 6.25 mm base, a nominal 1.75 x 3.75 mm top, and 0.8 mm fillets at the top, side corners and concave junction with the plate. The sides are 45 degrees before rounding and the blended base extends slightly beyond the nominal footprint. The center, accepted direction and 1.25 mm projection are preserved. This replaces the narrower 0.3 mm blends in v048.

One replacement carrier. Unsliced STL and generic 3MF retain the existing side print orientation. Existing M5 mounting geometry, screw-head recesses and launcher receivers are preserved. Complete carrier is editable mesh geometry in Blender; STEP describes only the analytic ramp and a 0.01 mm root into the plate. Reference meshes are not printable parts. Revised launcher contact and retention remain physically untested. No printer dispatch.

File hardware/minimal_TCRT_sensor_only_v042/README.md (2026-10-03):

TCRT5000 sensor-only launcher mount v042

Only the sensor mount is redesigned. The M5 stays on the existing separate v040 launcher attachment. No M5 support, deck, mounting holes, risers or M5 electronics are included.

Measured old sensor: 31 x 13 x 1 mm PCB, 12 mm optical projection, 7 x 7 x 6 mm adjustment block. Thin side guides, four PCB seats and end stops locate the board. Two centered M2x4 screws hold a small U keeper that presses on four bare edge lands. The adjustment block and header are open.

Parts: 01 cradle, 02 launcher clip keeper, 03 sensor pressure keeper, two unchanged latches. Reuse the existing latches and two M2x5 countersunk clip keeper screws. This modified clip keeper moves its crossbar forward to clear the larger PCB solder envelope.

The five STL files are prototype manufacturing orientations. They are unsliced. Physical fit, screw preload, exact corner contact lands, wiring and optical clearance require a check.

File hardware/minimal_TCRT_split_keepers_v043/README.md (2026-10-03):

TCRT5000 sensor-only mount v043

User markup changes: remove the teal U crossbar; replace it with two separate screw-on clip caps, each with a clear round M2 hole and countersunk seat. Smooth only the gray plate, retaining the orange clip lips. Keep the exact QRE narrow/lowered underside: 0.5 mm trim per side and 1 mm center drop.

Old QRE front sensor relief is filled to the flat 5.4 mm center surface; the two outer gray shoulder indent floors are filled to their existing 6.4 mm height. TCRT seat and optical datum remain fixed.

Reuse the v042 sensor pressure keeper, two original launcher latches, two M2x4 sensor screws and two M2x5 countersunk clip screws. Print replacements: cradle + left clip cap + right clip cap. All six printable pieces are included in the unsliced STL package. The M5 carrier remains separate and unchanged.

Physical fit, screw preload and optical alignment remain unverified. No printer dispatch.

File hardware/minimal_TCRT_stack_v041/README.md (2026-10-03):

TCRT5000 minimal stacked alternate v041

Open measured 31x13x1mm board cradle on the v033 launcher base. Two centered M2x4 screws secure a removable keeper/M5 dock, pressing on four bare PCB edge lands. Existing launcher latches are reused; the crossbar moves ahead of the larger board to clear solder. Tighten the sensor keeper through its reinforced driver windows first. Then attach the M5 underneath with two M2x6 screws at the accessible front overhang.

This is a design prototype, not a sliced print package. Electronics are references, never print them. Physical contact lands, wire envelope and optical alignment require fit checking. The TCRT and QRE versions remain separate.

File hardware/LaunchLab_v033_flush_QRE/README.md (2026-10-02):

# LaunchLab v0.33 — narrower, lower sensor platform

The launcher-facing center step is trimmed 0.5 mm on each side (1 mm narrower overall). Its native left edge has sub-micron facet variations; the trim follows its fitted plane within 0.00044 mm. The entire central solid moves down 1 mm, including the flat floor, board lands, component relief, header-tail clearance and centered screw posts. The side clips, hinge beds and clip screw posts stay at their existing height. The outer shoulder clearance beside the narrowed step extends to its original Z4.78 ceiling.

The PCB pocket still has 0.12 mm clearance per edge and a 9.24 mm opening for the 9 mm board. The PCB seat moves from Z6.4 to Z5.4; the nominal optical face moves from Z4.1 to Z3.1. The board, optics, resistors, upright Dupont plugs, sensor screws and pressure plate all move down by exactly 1 mm, retaining their prior relative clearances. The separate M5 platform is unchanged. The previous launcher-top reference is a CAD datum, not a measured model of the installed black launcher surface.

Only `01_QRE_minimal_port` needs printing. Reuse the v0.32 centered pressure plate, thicker latch crossbar, original left/right latches, separate M5 platform and four screws. The reused parts' manufacturing STLs are byte-identical to v0.32; the pressure plate has a lower assembly pose in this release. Older end-screw pressure plates do not match the centered posts.

The new base slice estimates 40m 1s and 5.59 g of PLA, including 1.96 g of support. All 216 model layers have deposition, and the adjacent layers on both sides of each thin center join deposit material through the 0.62 mm overlap.

A local Bambu P1S / PLA project contains only the new base, on its existing side print orientation, with 0.2 mm layers, Arachne walls and Tree Slim supports. Filament 3 is the requested dispatch mapping, not an assignment implied by the local slice. No printer dispatch.

Real Blender views and an editable STEP assembly show the actual exported geometry and nominal electronics. Digital checks include requested dimension changes, valid single-solid CAD, watertight mesh, unchanged outer mounting regions and hinges, original latch motion, board capture, screw access, component clearances and saved slicer geometry. The center-to-side joining height at the flat shoulder is 0.62 mm. Installed launcher clearance, printed strength and actual optical response require a physical fit check.

Source BP Gear Port: Migbello, Thingiverse 6856080, CC BY-SA (version unspecified). See `references/QRE_BP_port_LICENSE.txt` and `LICENSE.txt`.

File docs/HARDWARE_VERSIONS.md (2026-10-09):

# Hardware and sensor versions

LaunchLab Mini is a removable Beyblade X launcher-shaft RPM meter. **QRE1113** is the small analog sensor; **TCRT5000 / LM393** is the older, larger analog module. Their mounts and detector thresholds differ. The M5StickS3 carrier is a separate part with its own version history.

## Sidecar form factor

**Sidecar** is the LaunchLab form factor with the M5StickS3 mounted on its own carrier beside a separate optical sensor attachment. Sidecar supports either QRE1113 or TCRT5000; the name describes the mounting layout, not the sensor, firmware or hardware revision.

Pair the separate M5 carrier with the matching sensor attachment listed below. Follow each revision’s assembly instructions.

## Choose a sensor and firmware

| Sensor | Mount | Firmware | Status |
| --- | --- | --- | --- |
| Small analog QRE1113 | v0.33 sensor geometry / v0.40 complete six-piece plate | [0.11.1 firmware](../firmware/releases/0.11.1-sticks3-qre1113-themesbackup/README.md), QRE / Standard profile | User-checked prototype: 80 MHz, latest-launch tilt recap, history, trends, battery, display flip, themes and USB backup; endurance and recovery unverified. |
| Old TCRT5000 / LM393 analog AO | Latest v0.43 separate sensor attachment; v0.19 historical integrated mount | [0.11.1 firmware](../firmware/releases/0.11.1-sticks3-qre1113-themesbackup/README.md), TCRT5000 profile; frozen [0.2.0 TCRT firmware](https://github.com/shadohead/launchlab-mini/releases/tag/firmware-tcrt5000-v0.2.0) | 0.11.1 with the 60-count TCRT5000 profile is recommended; a TCRT5000 setup detected six of six pulls on that profile (0.10.17), which is unchanged since. 0.2.0 remains the earlier acquisition build. |

The web updater selects **0.11.1** for either sensor, with **0.10.22**, **0.10.21**, **0.10.14**, **0.10.11**, **0.10.7** and **0.10.1** retained for deliberate rollback. [Update and qualification details](UPDATER.md). Choose the Sensor profile in Settings after installing. The updater does not restore the old TCRT 0.2.0 build. Old firmware is an application-only restore at `0x10000` on an M5StickS3 already provisioned with the LaunchLab partition layout. Its exact binary retains runtime string `0.2.0-sticks3-acquisition`. See [TCRT wiring and restore guide](TCRT5000.md).

## Current downloads

- **Preferred separate M5 v0.68 carrier:** [assembly and source](../hardware/M5_cable_hook_v068/README.md), [complete package](../hardware/M5_cable_hook_v068_package.zip), [sliced P1S PLA 3MF](../hardware/M5_cable_hook_v068/bambu/LaunchLab_v068_P1S_PLA_M5_ATTACHMENT_PROTOTYPE.3mf), [carrier STL](../hardware/M5_cable_hook_v068/stl/01_M5_channel_two_humps_cable_hook.stl), [editable Blender model](../hardware/M5_cable_hook_v068/LaunchLab_v068_M5_underside_cable_hook.blend).

v0.68 is the project owner's preferred separate M5 carrier. It combines the
side-open wire channel, two older support humps and a downward-opening underside
hook shortened from 8 to 6 mm, retaining its 4.8 mm height. Its P1S PLA slice is
43m33s / 8.38 g. Three nominal 1.3 mm leads fit staggered in two rows and load
separately; connector housings stay outside. Physical seating, screw engagement,
hook strength, retention and launcher clearance remain unverified. The older
nominal M5 underside overlap is retained; dry-fit the actual device. This is a
single-carrier replacement, separate from the sensor mount and stacked layouts.

Earlier published options:

- [M5 v0.50 release](https://github.com/shadohead/launchlab-mini/releases/tag/hardware-m5-v0.50): [complete package](../hardware/M5_equal_supports_v050_package.zip), [sliced P1S PLA 3MF](../hardware/M5_equal_supports_v050/bambu/LaunchLab_v050_P1S_PLA_M5_EQUAL_SUPPORTS_TREE_SLIM.3mf), [unsliced project](../hardware/M5_equal_supports_v050/M5_equal_supports_v050_UNSLICED.3mf), [carrier STL](../hardware/M5_equal_supports_v050/stl/01_M5_equal_supports_platform.stl).
- [TCRT v0.43 release](https://github.com/shadohead/launchlab-mini/releases/tag/hardware-tcrt5000-v0.43): [six-piece package](../hardware/minimal_TCRT_split_keepers_v043_package.zip), [per-part STLs](../hardware/minimal_TCRT_split_keepers_v043/stl/), [full STEP assembly](../hardware/minimal_TCRT_split_keepers_v043/TCRT_split_keepers_v043.step). Unsliced CAD prototype; no saved 3MF exists for this revision.
- [QRE v0.40 complete plate](../hardware/LaunchLab_v040_ALL_ITEMS_PRINT/bambu/LaunchLab_v040_P1S_PLA_ALL_ITEMS_ONE_PLATE.3mf): existing six prints with the v0.40 M5 carrier. The v0.68 and v0.50 carriers are separate replacements, not included on that older plate.

**M5 v0.50 is a prototype:** its two supports rise from 0.5 to 2.3 mm to match the screw standoffs. The original nominal device reference has a stepped underside and overlaps these raised pads. Physical seating and leveling remain unverified. Its saved slice is 43m18s / 9.24 g PLA, Tree Slim supports; this is a slicing result, not proof of printing or fit. Re-slice for your printer and loaded filament. M2 screw length/insert engagement must be checked; the v0.45 counterbores changed the engagement of the earlier M2×6 reference. Do not infer a confirmed screw length from that reference.

**TCRT v0.43 is a prototype:** its PCB measurements are 31×13×1 mm, with provisional header/solder/head envelopes. Sensor alignment, solder clearance, screw preload and removable launcher retention require physical checks. The M5 mount remains separate. These newer mounts do not inherit the old firmware trial's physical validation.

## Revision history

Every row links to a frozen local snapshot with source files, manufacturing STLs, reference meshes, original README, attribution and digital reports. Whole M5 carriers are mesh geometry: their STEP files contain only the added pads, cutters or ramp named in that revision, not the entire carrier. TCRT v0.43 includes full per-part STEP files.

| Version | Family | Changes | Saved print state |
| --- | --- | --- | --- |
| [v0.19](../hardware/LaunchLab_v019_tcrt5000_open_stack/) | Old TCRT5000 | Historical open-stack integrated sensor/M5 mount. | Historical slice; physical fit unverified. |
| [v0.33](../hardware/LaunchLab_v033_flush_QRE/) | Small QRE1113 | Flush sensor base and preserved optical seat. | Included in v0.40 plate. |
| [v0.40](../hardware/LaunchLab_v040_ALL_ITEMS_PRINT/) | QRE + M5 | Complete six-piece plate with right-block M5 carrier. | Saved P1S PLA slice. |
| [v0.41](../hardware/minimal_TCRT_stack_v041/) | Old TCRT5000 | Minimal stacked cradle with removable sensor keeper/M5 dock. | Unsliced CAD prototype. |
| [v0.42](../hardware/minimal_TCRT_sensor_only_v042/) | Old TCRT5000 | Separate sensor-only attachment; M5 kept on its own carrier. | Unsliced CAD prototype. |
| [v0.43](../hardware/minimal_TCRT_split_keepers_v043/) | Old TCRT5000 | Independent left/right screw-on clip caps; smooth narrow lower plate. Six printed pieces. | Unsliced CAD prototype. |
| [v0.44](../hardware/M5_level_support_v044/) | M5 carrier | Opposite-end 0.5 mm supports for stepped device underside. | Unsliced STL. |
| [v0.45](../hardware/M5_recessed_screws_v045/) | M5 carrier | Underside screw-head counterbores, 4.2 mm diameter / 1.4 mm depth. | Unsliced 3MF/STL. |
| [v0.46](../hardware/M5_raised_rectangle_v046/) | M5 carrier | Center locating rectangle projection increased to 1.25 mm. | Unsliced 3MF/STL. |
| [v0.47](../hardware/M5_rotated_rectangle_v047/) | M5 carrier | Center rectangle rotated 90°, length extended. | Unsliced 3MF/STL. |
| [v0.48](../hardware/M5_smooth_rectangle_v048/) | M5 carrier | Sloped center rectangle with 0.3 mm rounded transitions. | Unsliced 3MF/STL. |
| [v0.49](../hardware/M5_soft_ramp_v049/) | M5 carrier | Broader center ramp with 0.8 mm fillets. | Unsliced 3MF/STL. |
| [v0.50](../hardware/M5_equal_supports_v050/) | M5 carrier | Opposite-end supports raised to 2.3 mm; v0.49 geometry retained. | Saved P1S PLA slice; seating unverified. |
| [v0.68](../hardware/M5_cable_hook_v068/) | M5 carrier | Preferred separate carrier: side-open channel, two older humps and 6 mm underside cable hook. | Saved P1S PLA slice; physical fit and strength unverified. |

[Machine-readable inventory and SHA-256 hashes](../hardware/versions.json) identify all newly published files. Older versions remain available; no published firmware binary or existing v0.40 geometry was replaced. One v0.42 render had a stale local checksum; its original checksum list is preserved under `provenance/`, and the publication list records the final saved render. All original CAD/STL/STEP hashes matched.

The [README exploded views](../README.md#exploded-assemblies) are rendered directly from these frozen STL meshes. Explosion distances and electronics/fastener references are illustrative. Digital CAD, archive and slicing checks do not establish printed fit, absolute RPM accuracy or launch-load retention.

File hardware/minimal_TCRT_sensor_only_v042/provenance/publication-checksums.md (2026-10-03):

The local v0.42 checksum file predated the final renders/03_exploded.png. All CAD/STL/STEP checksums matched. Original checksum file is preserved here; publication SHA256SUMS.txt records the current saved files. No geometry was changed.

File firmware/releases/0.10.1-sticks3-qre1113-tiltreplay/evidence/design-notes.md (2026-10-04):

# Readable orientation recap: 0.10.1

Research and offline UI revision, 2026-10-04. Not installed.

Garmin's attitude display distinguishes a reference horizon, aircraft symbol and
roll marker. The useful principle here is a stable reference for tilt, not copying
its cockpit numerical scales onto a 135×240 screen.
https://www8.garmin.com/manuals/webhelp/GUID-1FA95EDE-BA0A-4000-B109-7E73945389F7/EN-US/GUID-3C15377B-32FE-4604-A1BB-2B59E4205102.html

Xsens MT Manager section 5.7.3.1 uses a 3D sensor box to represent measured
orientation, and provides a playback toolbar separately from orientation data.
Its box illustration gives recognizable faces and axis cues. For this launcher,
a screen inset and USB cap identify the physical object without X/Y/Z labels.
https://www.xsens.com/hubfs/Downloads/Manuals/MT%20Manager%20User%20Manual.pdf

These are interface analogues, not evidence of user-tested readability on this
hardware. This revision applies their principles while keeping the user's cube,
neutral heading at the nearest middle edge and frozen Start/End tilt dots.

Changes:
- Larger fixed-scale body, tighter cube: ±0.84 display units contains the body's
  0.773-unit bounding sphere at every orientation. Same camera, no autoscaling.
- Quiet rear cage, brighter near edges, stationary middle-height reference lines
  and an up arrow. The display stays centered; no height/travel is inferred.
- Blue screen face, violet back, dark sides, screen inset and thick white USB cap.
  The USB cue is deliberately drawn last to remain visible in edge/back poses.
- Automatic recap draws one body. Gray reference endpoint appears only on the
  dedicated Motion page, where its meaning is labeled.
- Playback uses fused pose at optical onset (0 ms) through optical end
  (durationMs), with quaternion interpolation, rather than the full -500 ms to
  end+250 ms capture. Initial physical tilt is preserved. The retained full
  capture still supports comparison and storage; no sensor data are discarded.
- 1.8-second replay, followed by frozen end pose for the rest of the existing
  five-second recap. Progress marker makes the animated/frozen stages visible.
- Start/End dots retain recorded onset/end tilt throughout. Label spacing fixed;
  unavailable/pending capture now has a plain explanation rather than an empty box.

The scene's middle-height line is a gravity/attitude reference. It is not a
measured travel path, height, velocity or absolute compass heading. The IMU
estimator, acquisition, RPM modes, histories, power settings and tournament
views are unchanged. No angles/degrees clutter added to automatic recap.

Validation: actual MotionUI drawing primitives rendered offline for 37 playback
frames, five phase snapshots, 18 extreme-axis poses and unavailable/capturing
states. SVG/PNG/GIF use approximate host font metrics; exact device fonts and
physical acceptance remain pending. Preview is an illustrative synthetic launch,
not a recorded physical pull. Native replay tests cover smooth/clamped sampling,
exact onset/end orientation, initial tilt, yaw invariance, no acceleration-based
travel, fixed cube and body containment. Launch-motion regressions also pass.
A firmware build is retained in build.log. No USB commands or flash performed.

Reproduce host previews from repository root:
  c++ -std=c++17 firmware/tools/render_m5_motion_ui.cpp -o /tmp/render-m5-motion
  /tmp/render-m5-motion firmware/evidence/sticks3-0.10.1-tiltreplay

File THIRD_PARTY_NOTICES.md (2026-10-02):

# Attribution

- BP Gear Port Connector: Migbello, [Thingiverse 6856080](https://www.thingiverse.com/thing:6856080), Creative Commons Attribution Share Alike; version unspecified in the supplied notice. LaunchLab modifications include the adapter, latch bridge, optical cradle, pressure plate and M5 mount. Preserved notices accompany the hardware. No endorsement is implied.
- [VQF](https://github.com/dlaidig/vqf), Daniel Laidig and Thomas Seel: MIT; vendored commit `86ba56bdd3158b9b05f9f9fe5596866ba326438c` with copyright headers and license intact.
- [M5Unified](https://github.com/m5stack/M5Unified) 0.2.23 and [M5GFX](https://github.com/m5stack/M5GFX) 0.2.30: retain upstream MIT licenses when downloaded by the build.
- [Arduino ESP32](https://github.com/espressif/arduino-esp32) 3.3.0: upstream LGPL-2.1 and component licenses apply. Toolchain sources are obtained by the build script; compiled firmware includes these components.
- [esptool-js](https://github.com/espressif/esptool-js) 0.7.0: Apache-2.0; installed and bundled with its dependency licenses by npm/Vite.
- [spark-md5](https://github.com/satazor/js-spark-md5) 3.0.2: MIT.

Google Fonts serves DM Sans and Space Grotesk under the SIL Open Font License. USB data stays on the client; no analytics or device-data uploads are implemented.

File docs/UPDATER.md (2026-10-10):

# Update, repair and rollback

The latest release is **0.11.2**, runtime `0.11.2-sticks3-score-preview`. Previous **0.11.1**, **0.10.22**, **0.10.21**, **0.10.14**, **0.10.11**, **0.10.7** and **0.10.1** remain selectable; the withdrawn 0.11.0 is recognised as an installed application so it can be updated, but is not offered. These files target M5StickS3 K150 with an analog QRE1113 or TCRT5000 sensor: after installing, choose Menu → Settings → Sensor profile. The old TCRT 0.2.0 build remains separate. **0.11.1** is the user-checked prototype revision. It adds saved themes (Classic, Mint, Amber, Violet), a personal-best effect on the recap, and USB backup and restore of history, personal bests, appearance and settings (`K` export, `R` restore). It fixes 0.11.0, which restarted about once a second after boot (a loop-task stack overflow) and was withdrawn. One firmware still serves both sensors through the saved **Sensor profile** setting (QRE / Standard with an 80-count mark floor, TCRT5000 with 60). It was installed app-only on the owner's M5StickS3 K150: no restarts in a 120 s soak, history kept, a backup and restore round trip identical, and the screen, themes and pulls confirmed. The detector, sampling, thresholds and saved history format are unchanged from 0.10.22, which keeps measuring pulls that start right after an automatic save. Battery endurance, long-session reliability, absolute RPM/angle calibration, physical browser transfer and first install/rollback, and stock recovery remain separate checks. See [recovery guidance](RECOVERY.md).

0.11.2 adds the same-page High score effect sample in Settings and its editor. The owner approved local candidate `39ce90a` after testing it. Its compiled source differs from final 0.11.2 only in the runtime version string; this final binary has not been flashed again. Released 0.11.1 and the distinct tested development identity are recognized. The updater verifies the complete application MD5 after writing and requires deliberate Repair / rollback for a different build sharing the same version.

1. Save important history/settings and a private full-device backup before flashing. There is no automatic browser backup. Do not upload a full flash dump to an issue.
2. Open the USB updater in desktop Chrome or Edge with a data cable. Read the selected target version and confirm K150.
3. Choose **Update existing LaunchLab** for a normal application update. Connect USB with the M5 powered on and close other serial apps. The updater attempts to enter download mode automatically. If connection fails, hold the side Power/Reset button with USB connected until the green LED flashes, release it, then retry and select the download-mode port.
4. Connect. The updater checks every downloaded file's SHA-256, the bundle's fixed partition map, the detected chip and 8 MB flash capacity, the actual device partition and boot-selection bytes, and the installed application identity plus complete device MD5. The device label remains necessary for K150 confirmation.
5. An older target is blocked. An unknown or incomplete application is blocked. If the selected exact application is already installed, no flash is written.
6. After a verified write/no-op, restart automatically or use the side button when prompted. Check the runtime version, history/settings, references, READY state and an ordinary pull afterward.

## Repair or intentional rollback

Use **Repair / rollback** only after backup and a deliberate version choice. The checkbox names the selected target; changing the version or mode, or completing an attempt, clears consent. Repair can rewrite an interrupted application or intentionally install the previous 0.10.1. It writes **only the application at 0x10000**, retaining the data and boot areas; it cannot guarantee that older firmware understands newer data.

Both Update and Repair stop for a different partition layout or boot selection. This updater only supports its original app0 boot layout. It does not guess which slot an external OTA tool selected. Do not use First install merely to bypass these checks.

If USB disconnects during an app-only write, success is not reported. Re-enter download mode and reconnect. Normal Update will stop if the application is incomplete; deliberately confirm Repair for the intended target. Each attempt releases its connection before retry. Keep USB connected through device verification. A device MD5 failure is an error, not success. For an interrupted First install or persistent layout/connection failure, follow the [recovery guide](RECOVERY.md).

## First install

First install requires a separate explicit backup/factory-overwrite confirmation. It writes bootloader **0x0**, partitions **0x8000**, boot support **0xe000**, and application **0x10000**. No mode uses erase-all. It changes the layout and can make prior factory applications/data inaccessible even though these write ranges do not directly address the new NVS region.

The partition-table image is limited to its 4 KB slot ending at `0x9000`; the gap before boot support contains NVS and is not a writable part of that slot. The downloaded map and its embedded MD5 must match the reviewed 8 MB layout. Detected capacity must be exactly 8 MB in every mode. Checksums and capacity checks cannot prove the board model or guarantee interruption recovery.

## Return to M5Stack software

Follow [Recovery and M5Stack software reinstall](RECOVERY.md) for the official M5Burner/StickS3 route, backup limits and failed-update steps. Vendor software reinstall does not restore original data/settings/calibration or identify the exact as-shipped demo. No vendor binary is hosted here; physical stock reinstall remains unverified.

## Verification scope

The final 0.11.2 application is 754,688 bytes, SHA-256 `edaec5c245b8bc0e9e543e53896885e00d4c78df3eca17de57175beeff99c01e`. Exact archived candidate bytes upgrade to it in software tests, and it rolls back to the preserved 0.11.1 image. The three supporting installation images are byte-identical to 0.11.1. These are software checks; this final versioned binary has not been installed again. Earlier releases had device readback and data-preservation checks, and the owner reports the local effect-preview candidate works.

Twenty-seven native suites, seven production harnesses and updater software tests cover acquisition, replay/storage scheduling, USB policy, target selection, downgrade refusal, same-version no-op, corrupted images, interrupted/repeated attempts, explicit repair, partition/boot mismatches, capacity refusal, verification failure and cleanup. **Physical browser transfer, four-image 0.11.2 first install and rollback remain unverified.** Byte checks do not calibrate launcher RPM, tilt, battery charge or mechanical fit. Battery savings and an 80 MHz battery shake-wake cycle remain unmeasured.

The browser connection now uses esptool-js's automatic reset selection, including native USB-Serial/JTAG reset, instead of requiring an already-running ROM bootloader. Native esptool and the deployed browser both successfully connected to the affected device, started the stub and detected ESP32-S3 with 8 MB flash. The browser's subsequent partition read timed out without writing flash. Preflight reads now request 256-byte packets with one unacknowledged packet at a time and consume/verify the trailing MD5 described in [Espressif's protocol](https://docs.espressif.com/projects/esptool/en/latest/esp32s3/advanced-topics/serial-protocol.html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). Tests cover truncated/oversized packets, missing or corrupt digests, timeouts and consecutive reads. Physical acceptance of this read adjustment is pending. Software tests also require automatic reset before inspection/writes and release the port after failure.

The current storage schema identifiers remain unchanged, while save/validation behavior has changed since 0.10.7. This is static compatibility evidence, not a physical rollback guarantee. Older releases lack some current startup/timing repairs or the CPU policy. Preserve your backup until the intended release passes a real check.

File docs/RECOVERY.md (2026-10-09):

# Recovery and M5Stack software reinstall

For **M5StickS3 / StickS3, SKU K150**, with ESP32-S3 and 8 MB flash. Do not use StickC, StickC Plus/Plus2, CoreS3 or a generic ESP32-S3 image. Chip/USB identity and flash capacity cannot establish the exact board model; check the product label.

**Physical browser recovery, stock reinstall and rollback remain unverified on our device.** Download mode provides a recovery route when available; it does not guarantee recovery from every interruption, electrical fault or chip security configuration. There is no zero-brick promise.

## If a LaunchLab update failed

1. Read the error and save the installation log. Before a write starts, the updater reports that this attempt wrote no flash. A write or MD5-verification failure may leave incomplete software.
2. Connect USB with a known data cable. Hold the side Power/Reset button until the internal green LED flashes. This is [M5Stack's K150 download-mode procedure](https://docs.m5stack.com/en/core/StickS3). Close other serial tools and select the download-mode port again.
3. If an **app-only Update** was interrupted, select the intended version and deliberately confirm **Repair / rollback** after backup. Repair writes app0 at `0x10000` only after checking the device's partition table and boot selection.
4. If either layout check fails, **stop**. Do not select First install to bypass it. Keep the backup and ask for a reviewed recovery choice.
5. If **First install** was interrupted, the bootloader, partition table or boot selection may also be incomplete. A deliberate retry of the same selected bundle can rewrite all four images; it needs the backup/overwrite confirmation again. Do not assume app-only repair will fix it. Persistent failure needs the vendor route below or support.
6. Keep USB connected through verification. After success, restart and check the intended runtime version, history/settings, READY behavior and ordinary pulls. Firmware byte verification does not prove reliable RPM, motion replay or power behavior.

There is no automatic erase-all, mode change or recovery write. Wrong chip, unknown/non-8 MB flash capacity, invalid bundle layout or mismatched device boot layout is a refusal. Changing the target/mode or finishing an attempt clears overwrite consent. Each attempt disconnects before retry.

## Reinstall M5Stack software

Use [official M5Burner](https://docs.m5stack.com/en/uiflow/m5burner/intro) and the [vendor's StickS3 UIFlow2 flashing guide](https://docs.m5stack.com/en/uiflow2/sticks3/program). Select **UIFlow2 firmware specifically for StickS3**. Enter download mode, choose the corresponding USB port and follow the tool's configuration/burn steps. Restart and verify the selected vendor software afterward. Review any erase/overwrite choice before accepting it.

This is a vendor software reinstall, **not a reconstruction of the unit's original factory state**. The exact demo and version shipped with a particular unit have not been verified. If you need that exact software, use your own pre-install backup or ask M5Stack to identify it. LaunchLab does not host third-party factory binaries or guess vendor flash offsets.

Reinstallation may replace or make earlier settings, history, Wi-Fi credentials and calibration inaccessible. Without a usable backup made before replacement, those original records cannot be recovered merely by reinstalling software. A backup also does not undo permanent chip security settings or repair damaged hardware.

After reinstalling vendor software, normal LaunchLab Update/Repair may refuse its different layout. Returning to LaunchLab is an intentional **First install**, with a new backup and overwrite confirmation.

## Before replacing software: keep a private backup

The browser updater does **not** save a backup. Record the model, existing firmware identity and important settings separately. Keep any full flash dump private; it can contain credentials and personal records. Do not attach it to an issue or commit it.

For users who already have Espressif's current esptool available, its [read-flash documentation](https://docs.espressif.com/projects/esptool/en/latest/esp32s3/esptool/basic-commands.html) supports a full K150 flash read. With the device in download mode, substitute its actual port:

```sh
esptool --chip esp32s3 --port PORT --baud 115200 read-flash 0 0x800000 sticks3-k150-before-install.bin
```

This reads flash; it does not erase or write it. Check successful completion, the expected **8,388,608 bytes**, and keep a checksum plus a second private copy. File length alone does not prove a restorable backup. A dump made after a failed write preserves the current state, not the already-overwritten original. Encrypted/secured devices can restrict reads or make a dump unsuitable for ordinary restoration; stop on security warnings and never use force flags to bypass them.

Restoring a whole-device backup needs a separate model, provenance and security review. This page deliberately offers no generic whole-flash write button. Use the official vendor route for a fresh vendor installation; ask for support before writing a private dump back.

## No port or repeated failure

Use a direct USB connection and another known data cable; close apps holding the port and re-enter download mode. Keep power steady. Check [Espressif's troubleshooting guide](https://docs.espressif.com/projects/esptool/en/latest/esp32s3/troubleshooting.html) if connection or verification keeps failing. If download mode remains unavailable, stop and contact support rather than repeatedly changing images or erasing flash.

For [LaunchLab support](https://github.com/shadohead/launchlab-mini/issues), include K150 identification, OS/browser, selected version/mode, the exact error, whether writing started, and a scrubbed installation log. Remove personal paths, port identifiers and other private details.

## Current release gate

**0.11.1** is the user-checked prototype revision. It adds saved themes (Classic, Mint, Amber, Violet), a personal-best effect on the recap, and USB backup and restore of history, personal bests, appearance and settings (`K` export, `R` restore). It fixes 0.11.0, which restarted about once a second after boot (a loop-task stack overflow) and was withdrawn. One firmware still serves both sensors through the saved **Sensor profile** setting (QRE / Standard with an 80-count mark floor, TCRT5000 with 60). It was installed app-only on the owner's M5StickS3 K150: no restarts in a 120 s soak, history kept, a backup and restore round trip identical, and the screen, themes and pulls confirmed. The detector, sampling, thresholds and saved history format are unchanged from 0.10.22, which keeps measuring pulls that start right after an automatic save. Battery endurance, long-session reliability, absolute RPM/angle calibration, physical browser transfer and first install/rollback, and stock recovery remain separate checks.

Local guard/instruction fixes do not qualify physical recovery. Preserve exact archives and private backups. Normal pulls/replay and app-only retention were checked on the development device. Still verify battery standby/wake at 80 MHz, USB suspend/detach behavior and interrupted browser update, vendor reinstall and rollback separately. Hidden secured wiring and assembly acceptance remain required before a buyer pilot.

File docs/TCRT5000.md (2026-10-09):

# Old TCRT5000 / LM393 sensor

[Parts list, quantities and purchase links](../README.md#parts-list--build-your-own) are at the top of the README.

The **Sidecar form factor** mounts the M5 on its own carrier beside this sensor attachment. Sidecar describes the mounting layout; select firmware for the sensor you actually use.

This is the older, larger blue analog sensor module, separate from the small QRE1113 build. Use its **analog AO** output. DO remains disconnected. The current **0.11.1** firmware supports it directly: install it with the [web updater](https://shadohead.github.io/launchlab-mini/), then choose **Menu → Settings → Sensor profile → TCRT5000**. There is no sensor auto-detection. The frozen **0.2.0-sticks3-tcrt5000** firmware remains available below.

| TCRT5000 module | M5StickS3 K150 Hat |
| --- | --- |
| AO | G1 / GPIO1 |
| VCC | 3V3 / 3V3_L2 |
| GND | GND |

Verify your module's physical pin labels. Do not power it from the 5 V Grove red lead or use GPIO0 as the analog input. The TCRT5000 profile (unchanged since 0.10.18, current in 0.11.1) uses a 60-count minimum mark, for this module's weaker marks, with 70% reversal hysteresis at 50 kS/s; a TCRT5000 setup detected six of six physical pulls on it. The old 0.2.0 build uses an 80-count minimum.

## Printed mount

[v0.43](../hardware/minimal_TCRT_split_keepers_v043/) is the latest sensor-only CAD prototype: cradle, two separate screw-on clip caps, pressure keeper and both launcher latches. Use 2×M2×4 pan-head screws for the sensor keeper and 2×M2×5 countersunk screws for the clip caps, checking actual preload and engagement after printing. M5 is on a separate carrier. STLs are in manufacturing orientations; preview STLs and STEP files retain assembly poses. There is no saved sliced 3MF for v0.43. Import the six manufacturing STLs, position, slice and inspect them for your printer.

The earlier [v0.19](../hardware/LaunchLab_v019_tcrt5000_open_stack/), [v0.41](../hardware/minimal_TCRT_stack_v041/) and [v0.42](../hardware/minimal_TCRT_sensor_only_v042/) are preserved as historical alternatives. See [all hardware versions](HARDWARE_VERSIONS.md).

## Restore the saved old-sensor application

Download the [old TCRT firmware release](https://github.com/shadohead/launchlab-mini/releases/tag/firmware-tcrt5000-v0.2.0). This is an application-only image for an M5StickS3 K150 that already has the LaunchLab `default_8MB` partition layout. It is not a factory-board first-install bundle. The browser updater installs the current 0.11.1 firmware, not this old build.

With Espressif esptool installed, enter download mode and replace `YOUR_SERIAL_PORT` with the device's port:

```sh
python3 -m esptool --chip esp32s3 --port YOUR_SERIAL_PORT --baud 460800 \
  write-flash 0x10000 firmware/releases/0.2.0-sticks3-tcrt5000/LaunchLabMini.ino.bin
```

Preserve the bootloader/partitions and verify the device write checksum. The saved image is 619,408 bytes and its SHA-256 is `8f60898d0a4fd3e9e6cf16c741ada3ac50949d21f52ab84574b8c54e09a5dec6`. The runtime version still reads `0.2.0-sticks3-acquisition`; it was not rebuilt or retuned for publication.

The original trial had three user-confirmed pulls, three device detections and three saved-waveform replay results. It is not independent absolute RPM calibration and does not validate the newer printed mounts. This earlier acquisition build does not supply the QRE 0.7.0 history/trend/Motion/Recreate UI shown in the README. Historical READMEs retain development-era commands and private evidence references; those backups and practice captures are not part of the public package. Use this guide for public restore paths.

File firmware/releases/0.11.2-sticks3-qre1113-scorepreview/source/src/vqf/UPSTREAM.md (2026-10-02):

# VQF

Unmodified `vqf/cpp/vqf.hpp` and `vqf/cpp/vqf.cpp` from
https://github.com/dlaidig/vqf, commit
`86ba56bdd3158b9b05f9f9fe5596866ba326438c`.
MIT license in `LICENSE`; copyright and SPDX headers retained.

Paper: Laidig and Seel, Information Fusion 91 (2023), 187–204,
https://doi.org/10.1016/j.inffus.2022.10.014.

Both firmware and native tests compile with `VQF_SINGLE_PRECISION`.
Upstream keeps the Butterworth filters in double precision.
The LaunchLab wrapper resamples measured timestamps to 100 Hz and uses
6D orientation only. No magnetometer, position, or absolute heading is supplied.

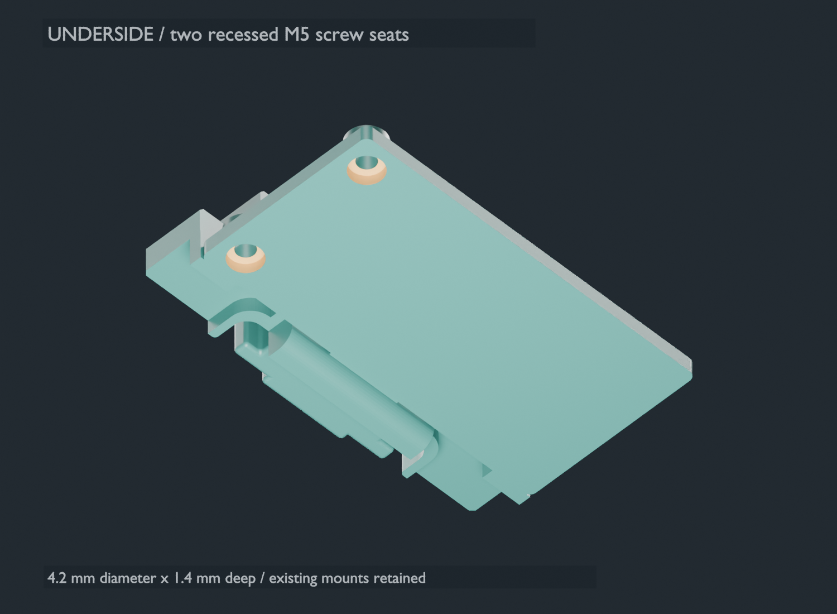
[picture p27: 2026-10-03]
hardware/M5_recessed_screws_v045/renders/01_underside_recesses.png

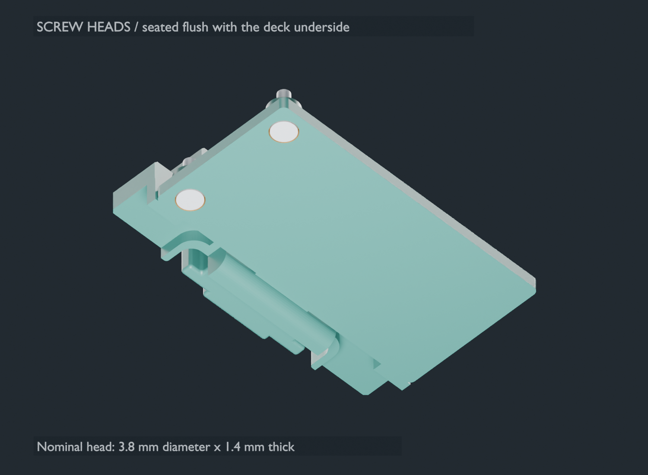
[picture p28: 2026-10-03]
hardware/M5_recessed_screws_v045/renders/02_flush_heads.png

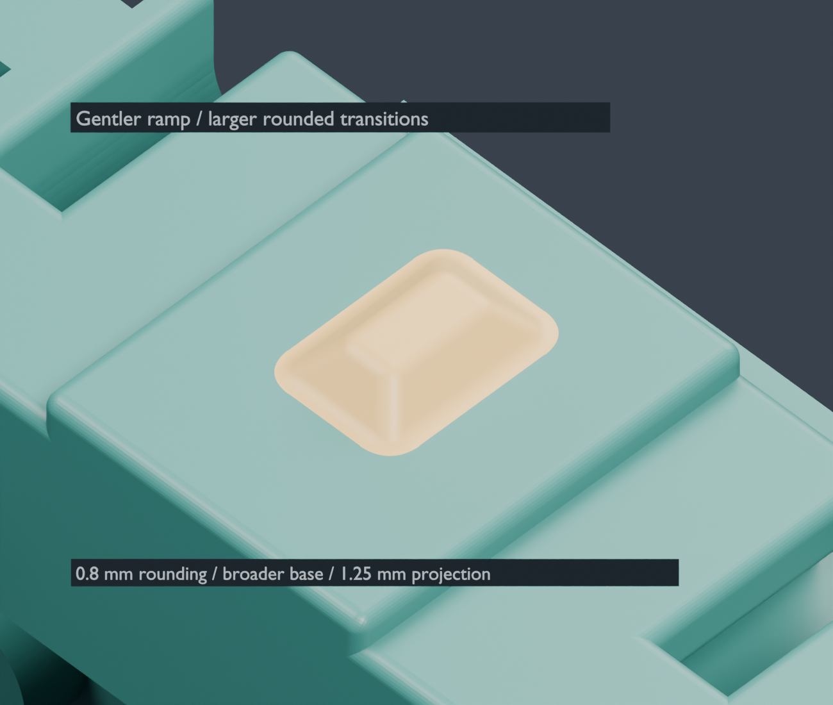
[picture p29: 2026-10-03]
hardware/M5_soft_ramp_v049/renders/02_revised_closeup.png

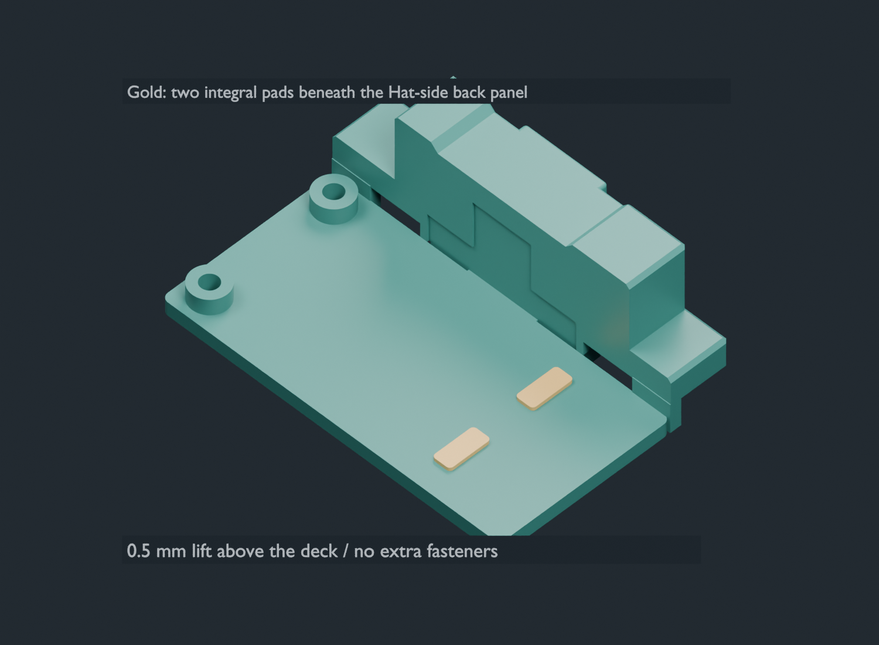
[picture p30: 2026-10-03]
hardware/M5_level_support_v044/renders/02_bare_supports.png

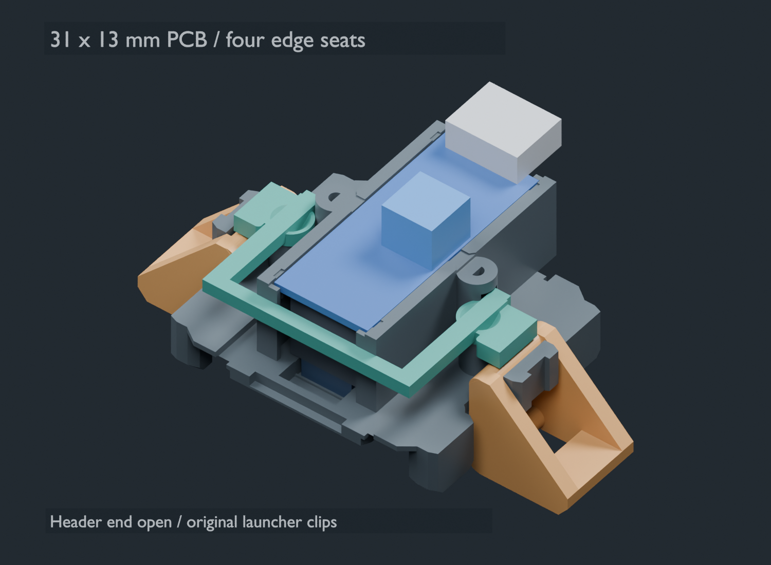
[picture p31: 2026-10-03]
hardware/minimal_TCRT_stack_v041/renders/02_sensor_cradle.png

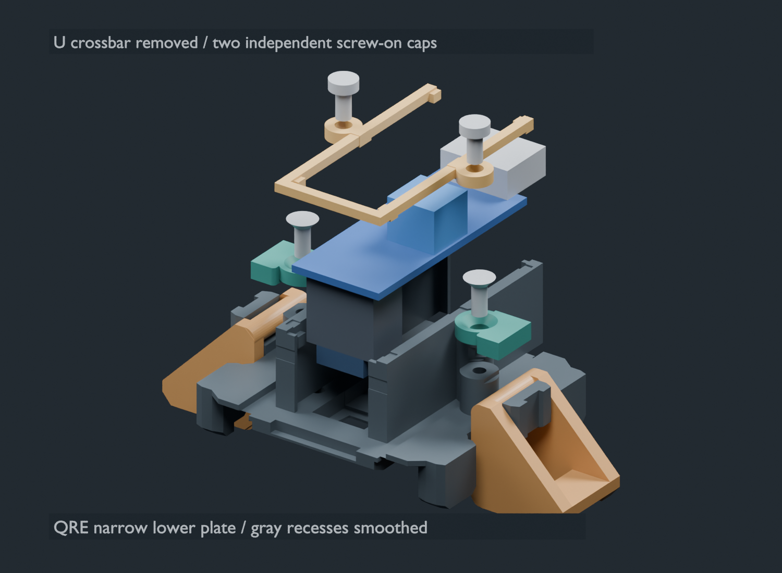
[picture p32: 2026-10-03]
hardware/minimal_TCRT_split_keepers_v043/renders/03_exploded.png

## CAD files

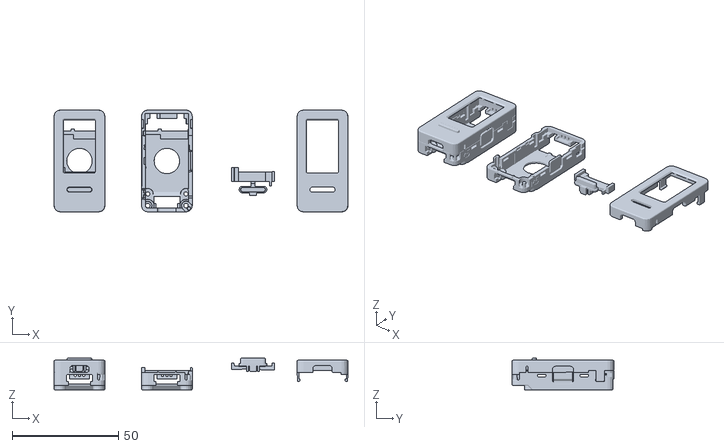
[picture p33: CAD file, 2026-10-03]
hardware/LaunchLab_v019_tcrt5000_open_stack/references/StickS3_VENDOR_ASSEMBLY_AND_EXPLODED.stl
138.5 x 48.0 x 15.0

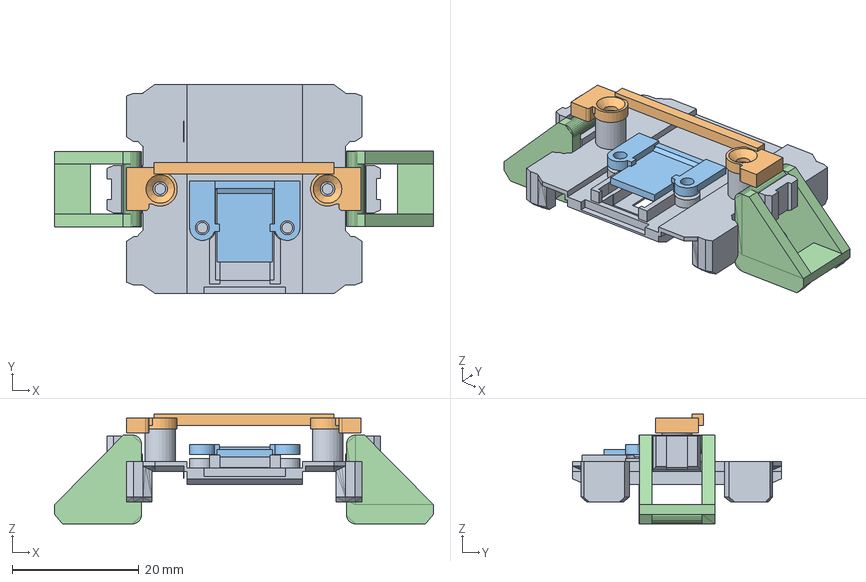
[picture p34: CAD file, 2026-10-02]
hardware/LaunchLab_v033_flush_QRE/LaunchLab_v033_flush_QRE_assembly.step
59.8 x 33.0 x 17.3 mm

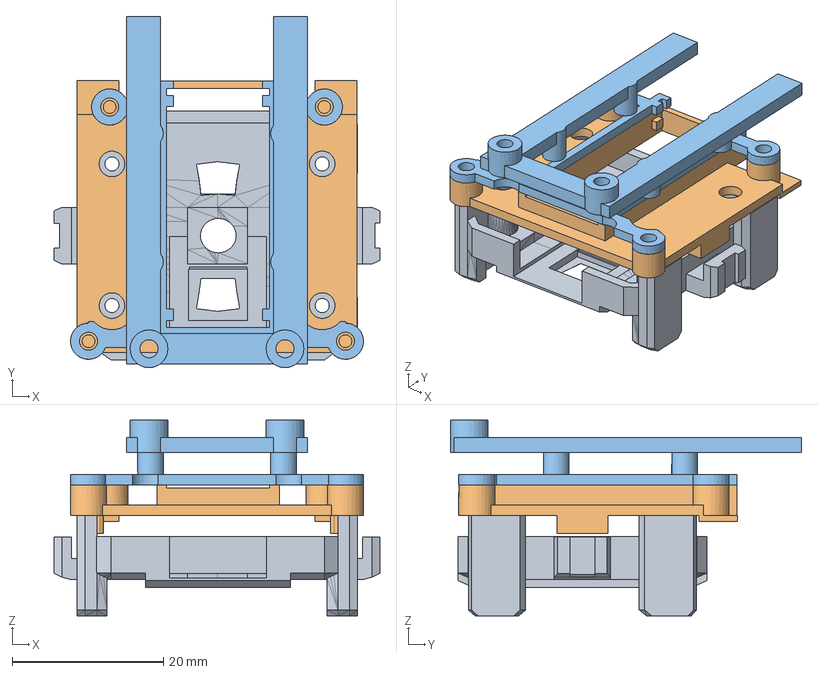
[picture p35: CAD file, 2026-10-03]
hardware/LaunchLab_v019_tcrt5000_open_stack/LaunchLab_v019_TCRT_open_stack_assembly.step
43.1 x 46.5 x 25.9 mm

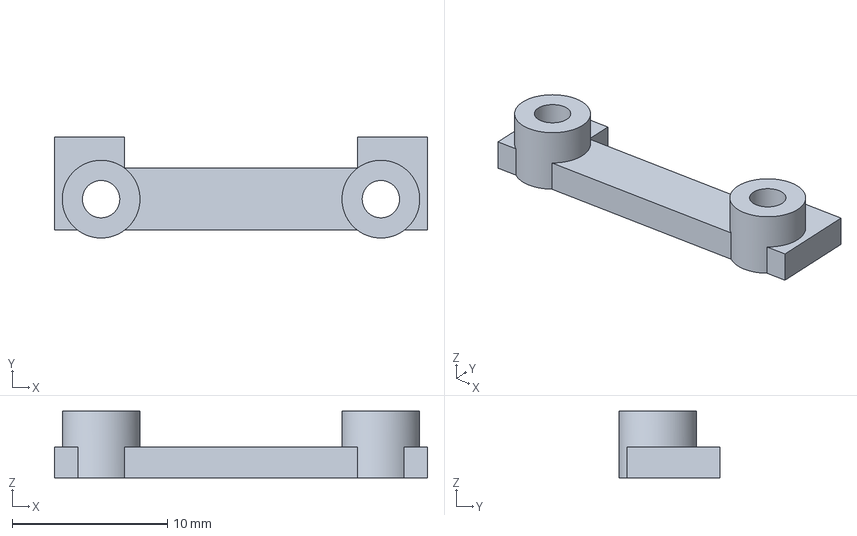
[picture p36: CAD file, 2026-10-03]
hardware/LaunchLab_v019_tcrt5000_open_stack/bambu/LaunchLab_v019_P1S_PLA_M5_MOUNT_FIT.3mf
24.0 x 6.50 x 4.30 mm

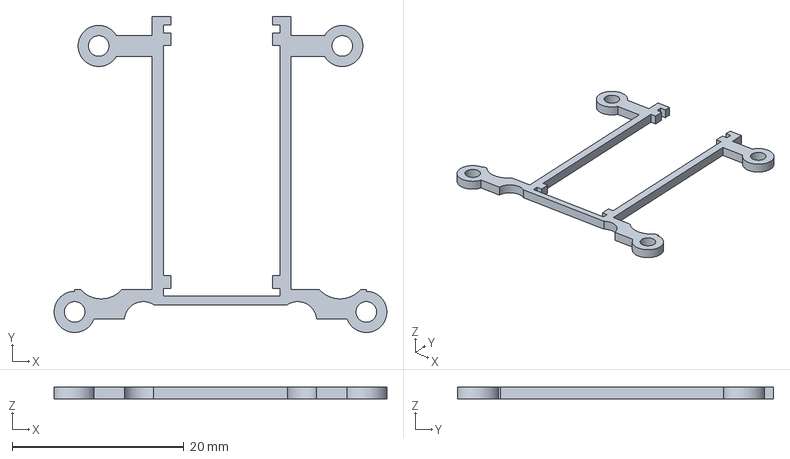
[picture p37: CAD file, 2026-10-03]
hardware/LaunchLab_v019_tcrt5000_open_stack/extras/12_TCRT_KEEPER_FIT.step
38.8 x 36.8 x 1.40 mm

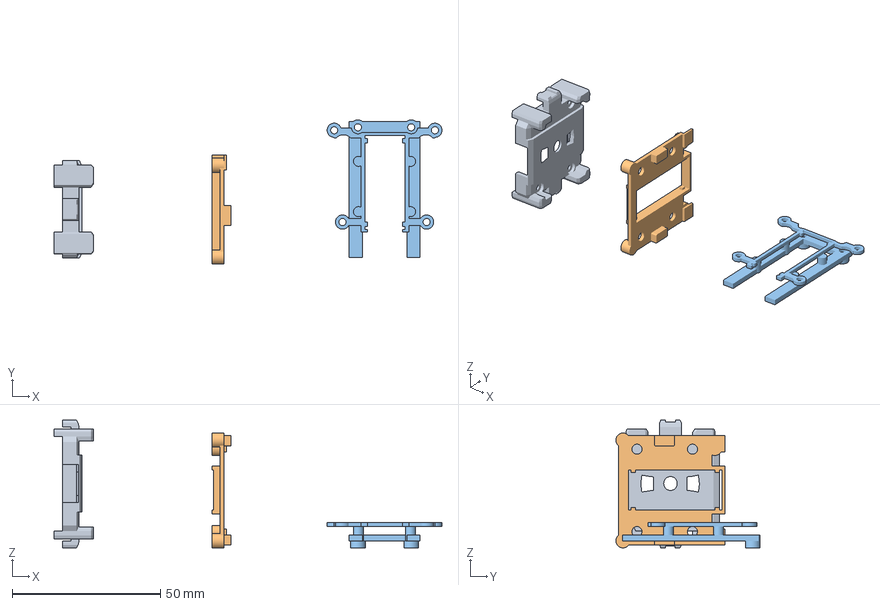
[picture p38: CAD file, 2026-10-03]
hardware/LaunchLab_v019_tcrt5000_open_stack/LaunchLab_v019_REPLACEMENTS_UNSLICED.3mf
131.0 x 48.7 x 43.1 mm
01_TCRT_attachment_port.001
03_TCRT_sensor_cradle.001
04_TCRT_M5_top_dock.001

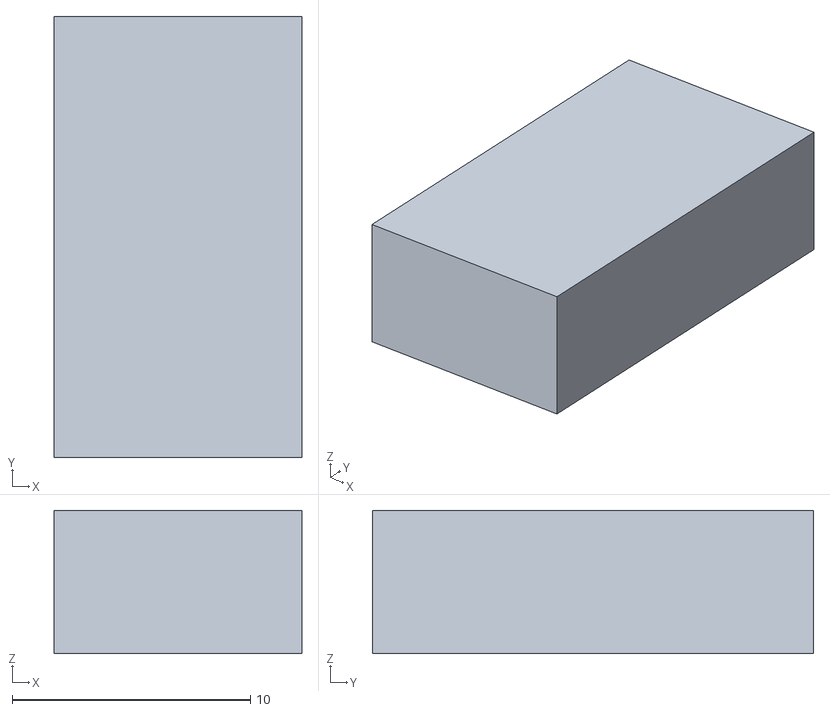
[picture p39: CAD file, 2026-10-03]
hardware/LaunchLab_v019_tcrt5000_open_stack/preview/REF_SENSOR_SOCKET_ALLOWANCE.stl
10.4 x 18.5 x 6.00

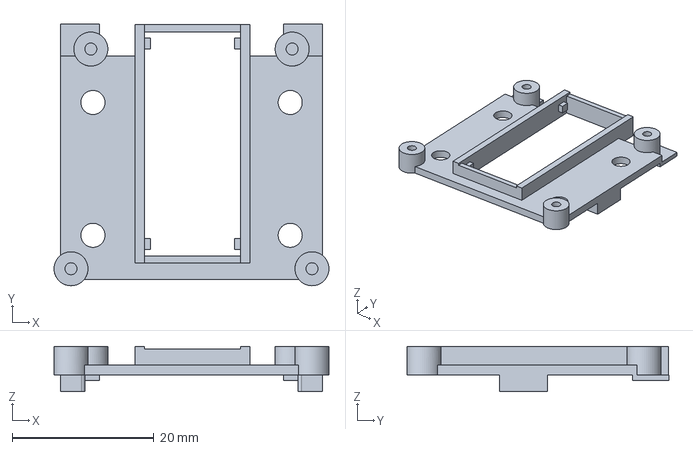
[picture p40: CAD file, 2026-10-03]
hardware/LaunchLab_v019_tcrt5000_open_stack/step/03_TCRT_sensor_cradle.step
38.8 x 36.9 x 6.40 mm

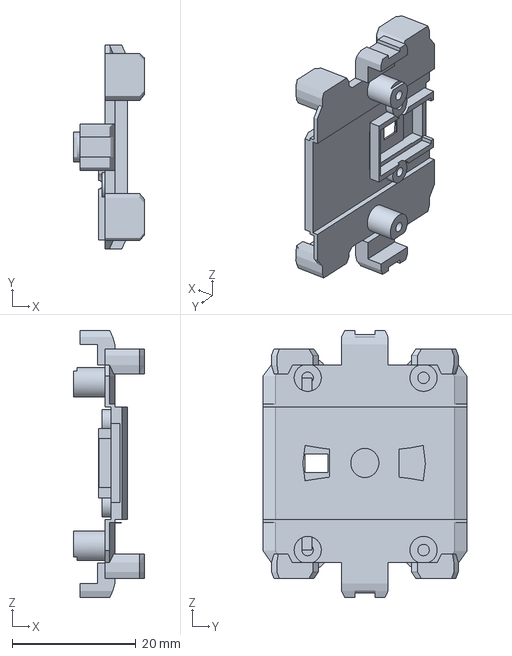
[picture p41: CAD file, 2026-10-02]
hardware/LaunchLab_v033_flush_QRE/bambu/LaunchLab_v033_P1S_PLA_BASE_TREE_SLIM.3mf
11.5 x 33.0 x 43.1 mm

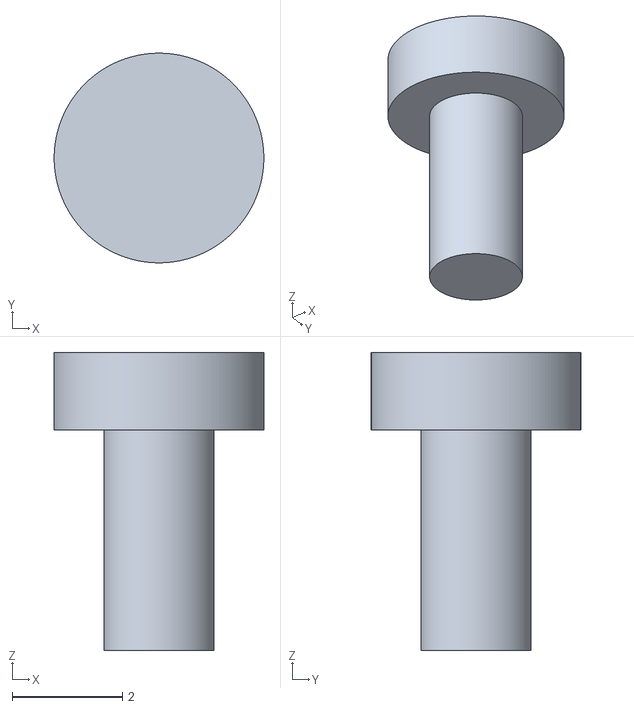
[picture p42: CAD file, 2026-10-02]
hardware/LaunchLab_v033_flush_QRE/preview/REF_M2x4_SENSOR_2.stl
3.80 x 3.80 x 5.40

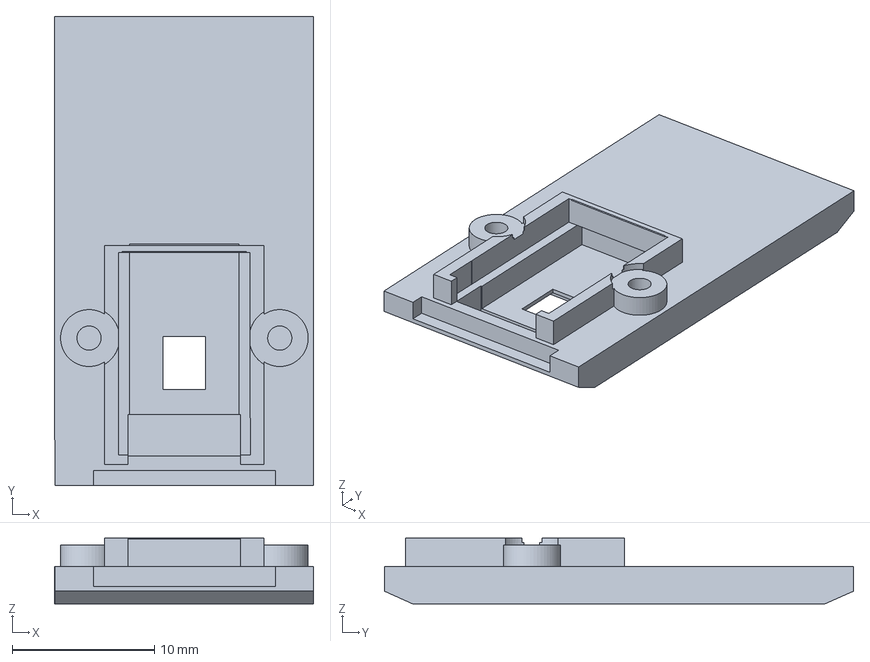
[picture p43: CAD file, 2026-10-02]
hardware/LaunchLab_v033_flush_QRE/references/REF_NEW_center.step
18.2 x 33.0 x 4.62 mm

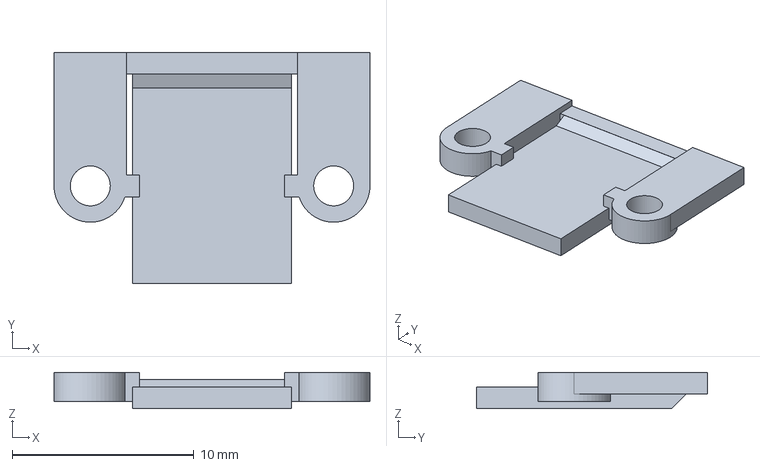
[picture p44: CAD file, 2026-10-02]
hardware/LaunchLab_v033_flush_QRE/step/03_QRE_pressure_bar.step
17.4 x 12.7 x 2.00 mm

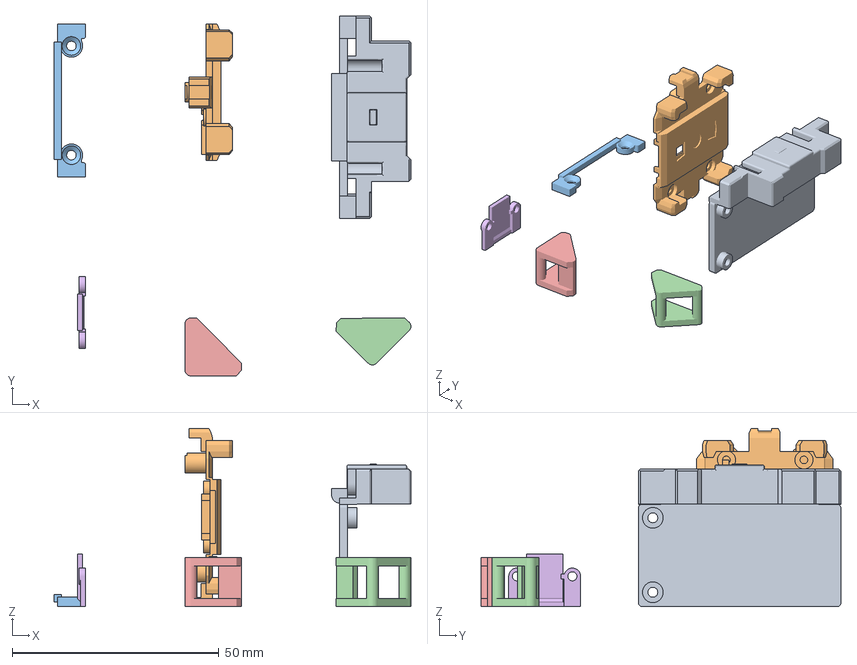
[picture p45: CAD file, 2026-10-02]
hardware/LaunchLab_v040_ALL_ITEMS_PRINT/bambu/LaunchLab_v040_P1S_PLA_ALL_ITEMS_ONE_PLATE.3mf
86.3 x 87.0 x 43.1 mm
01_M5_stepped_platform
01_QRE_minimal_port
02_QRE_clip_keeper
09_QRE_latch_RIGHT
08_QRE_latch_LEFT
03_QRE_pressure_bar

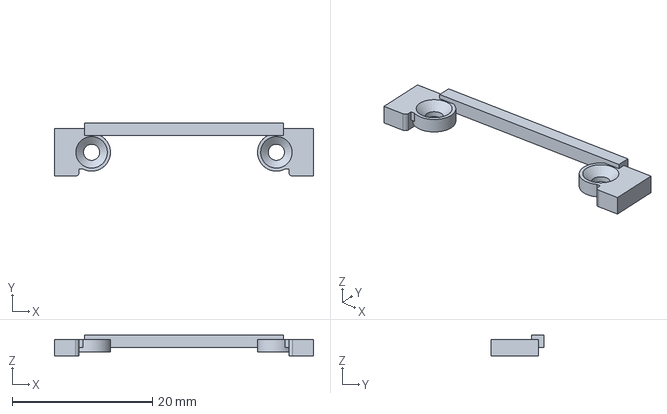
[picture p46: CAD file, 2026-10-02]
hardware/LaunchLab_v040_ALL_ITEMS_PRINT/step/02_QRE_clip_keeper.step
37.0 x 7.60 x 2.98 mm

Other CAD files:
hardware/LaunchLab_v040_ALL_ITEMS_PRINT/stl/01_M5_stepped_platform.stl
hardware/LaunchLab_v040_right_block_print/bambu/LaunchLab_v040_P1S_PLA_M5_RIGHT_BLOCK_TREE_SLIM.3mf
hardware/LaunchLab_v040_right_block_print/LaunchLab_v040_M5_RIGHT_BLOCK_TREE_SLIM_UNSLICED.3mf
hardware/LaunchLab_v040_right_block_print/preview/01_M5_stepped_platform.stl
hardware/LaunchLab_v019_tcrt5000_open_stack/LaunchLab_v019_ALL_PARTS_UNSLICED.3mf
hardware/LaunchLab_v019_tcrt5000_open_stack/LaunchLab_v019_CLIPS_UNSLICED.3mf
hardware/LaunchLab_v019_tcrt5000_open_stack/LaunchLab_v019_SENSOR_FIT_UNSLICED.3mf
hardware/LaunchLab_v019_tcrt5000_open_stack/LaunchLab_v019_tcrt5000_open_stack.blend
hardware/LaunchLab_v019_tcrt5000_open_stack/bambu/LaunchLab_v019_P1S_PLA_ALL_PARTS.3mf
hardware/LaunchLab_v019_tcrt5000_open_stack/bambu/LaunchLab_v019_P1S_PLA_CLIPS.3mf
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

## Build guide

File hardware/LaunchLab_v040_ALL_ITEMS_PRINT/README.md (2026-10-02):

# LaunchLab v0.40 complete print package

Open `bambu/LaunchLab_v040_P1S_PLA_ALL_ITEMS_ONE_PLATE.3mf` in Bambu Studio. It contains one plate with one of each of the six required printed parts:

- v0.33 QRE base, with the center step trimmed 0.5 mm per side and the center platform/sensor seat lowered 1 mm.
- v0.32 thicker latch crossbar.
- v0.32 centered sensor pressure plate, upright on its continuous flat edge.
- Left launcher latch.
- Right launcher latch.
- v0.40 separate M5 platform with the circled right block trimmed 3 mm left and its factory edge finish restored.

Only the M5 platform changes; reuse the five sensor parts if you already have them. The circled raised right block is shortened 3 mm toward the left in the top view with USB-C on the right. Its end changes from Y-18.5 to Y-15.5. The opposite edge's native 0.5 mm bevel, including its corner, is copied onto the new top edge. The lower launcher foot, curved receivers, M5 position, 2 mm deck, M2 mounting posts and other raised block are preserved. See `reports/M5_before_after.png` for a rendering of the actual meshes.

Settings: Bambu P1S, 0.4 mm nozzle, PLA, 0.2 mm layers, Arachne walls and 5 mm outer brims. Tree Slim supports are enabled globally, with supports explicitly disabled on the upright pressure plate. All six parts retain their manufacturing geometry and print orientations; auto-arrangement changes only their positions and rotation within the plate.

The slice estimates 1h 15m 59s and 18.04 g of PLA. Assign the project's single PLA filament to AMS filament 3 in the print dialog. This package has not been dispatched to the printer.

Nominal assembly hardware:

- 2 x M2x6 screws for the M5 platform, installed from underneath.
- 2 x M2x5 countersunk screws for the latch crossbar.
- 2 x M2x4 pan-head screws for the sensor pressure plate.

Individual STLs are included in `stl/`. Each matches its frozen source release byte-for-byte. The five QRE STEP files are included in `step/`; the M5 platform is supplied as a mesh. The saved 3MF is checked against all six source STLs, its G-code checksum and per-object settings are verified, and all models fit within one P1S plate. Actual model deposition is checked for every part, with no support deposition through the pressure plate's bounding box. Digital clearance checks pass; physical thumb reach, button operation and the trimmed mount's strength need checking after printing.

Source BP Gear Port and native grip: Migbello, Thingiverse 6856080, CC BY-SA (version unspecified). See `LICENSE.txt` and `references/QRE_BP_port_LICENSE.txt`.

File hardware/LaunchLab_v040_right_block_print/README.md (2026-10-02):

# LaunchLab v0.40 — trimmed M5 block with matching edge

The user-circled raised right block is shortened 3 mm toward the left in the
top view with USB-C on the right. Its end changes from Y-18.5 to Y-15.5.
The opposite end's native 0.5 mm bevel, including its corner, is copied onto
the new top edge. The lower launcher foot, curved receivers, M5 position,
2 mm deck, screw posts and the other raised block are unchanged.

Only the M5 carrier needs replacing. Reuse the v0.33 sensor assembly and
two M2x6 screws. Open the M5-only Bambu 3MF in bambu/ for P1S 0.4 mm,
PLA, 0.2 mm layers, Arachne, 5 mm outer brim and Tree Slim supports.
Assign the project's PLA to AMS filament 3 in the print dialog.
The individual manufacturing STL is in stl/; preview/ uses assembly coordinates.
No printer job has been started. Physical thumb reach and printed strength
still need checking after printing.

The editable Blender and GLB show actual part and factory M5 meshes.
Source: Migbello native grip / BP Gear Port, Thingiverse 6856080,
CC BY-SA (version unspecified). See LICENSE.txt.

Replacement slice estimate: 42m 46s, 9.16 g PLA. All manufacturing layers and the saved 3MF geometry/settings/G-code checksum pass digital checks.

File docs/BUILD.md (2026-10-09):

# Build a LaunchLab Mini Sidecar — small QRE1113 sensor

[Parts list, quantities and purchase links](../README.md#parts-list--build-your-own) are at the top of the README.

**Sidecar** is the LaunchLab form factor with the M5StickS3 mounted on its own carrier beside a separate optical sensor attachment. Sidecar supports either QRE1113 or TCRT5000; the name describes the mounting layout, not the sensor, firmware or hardware revision.

Use M5StickS3 **K150**, which has ESP32-S3, 8 MB flash, integrated display and battery. M5StickC/C Plus/C Plus2 use different hardware and are not supported by these images. The small sensor is the **analog QRE1113 breakout**; a digital-output board is not interchangeable.

For the **old TCRT5000 / LM393 module**, use [TCRT5000.md](TCRT5000.md). [Hardware versions](HARDWARE_VERSIONS.md) covers the preferred independent M5 v0.68 carrier and its unverified seating/fastener engagement. The original v0.40 plate below retains its earlier carrier.

## Parts and wiring

- One intact M5StickS3 K150 and one analog QRE1113 breakout.
- Three short signal/power wires, sized for your board/header. Confirm the physical connector pin labels before attaching power.
- Six printed parts from the v0.40 plate.
- Two M2×6 screws for the M5 platform, inserted from underneath.
- Two M2×5 countersunk screws for the latch crossbar.
- Two M2×4 pan-head screws for the sensor pressure plate.

| Sensor | M5StickS3 Hat |
| --- | --- |
| OUT / analog AO | G1 / GPIO1 |
| VCC | 3V3 / 3V3_L2 |
| GND | GND |

A seller's digital/analog label alone does not identify a compatible board. Capacitor-timing QRE boards require an active GPIO measurement sequence that this firmware does not implement. The MusRock B0FR9DBW4K listing contains conflicting output descriptions; its circuit and RPM accuracy remain unqualified.

Do not use GPIO0 for analog sampling. Do not use Grove red as a 3.3 V supply; it supplies 5 V. The firmware defaults to GPIO1 and does not automatically change the sensor supply or pin selection. Confirm your breakout's actual pin order and keep its output within 3.3 V logic limits.

## Printing and assembly

Open `hardware/LaunchLab_v040_ALL_ITEMS_PRINT/bambu/LaunchLab_v040_P1S_PLA_ALL_ITEMS_ONE_PLATE.3mf`. It contains the v0.40 M5 platform, v0.33 QRE base, v0.32 thicker crossbar, centered pressure plate, and both launcher latches. If upgrading an existing sensor attachment, only the M5 platform needs replacement.

The saved profile targets a P1S, PLA, 0.4 mm nozzle, 0.2 mm layers, Arachne walls, and 5 mm outer brims. Tree Slim support is enabled except on the upright pressure plate. Re-slice and review the plate for your own printer and filament. The original profile's AMS filament assignment is local metadata; select your own loaded filament. Estimate: 1h 15m 59s, 18.04 g.

Use the included exploded CAD/assembly references and per-part STLs. Keep the attachment removable, preserve the factory M5 enclosure, and inspect cable strain relief, sensor alignment, button/USB access and screw engagement before use. Check the printed launcher retention by hand before any pull. Digital checks do not establish physical fit or launch-load strength.

## Sidecar M5 carrier and cable routing

The [v0.68 separate M5 carrier](../hardware/M5_cable_hook_v068/README.md) replaces
the original M5 platform; reuse your sensor attachment. Print its supplied single
carrier [P1S PLA project](../hardware/M5_cable_hook_v068/bambu/LaunchLab_v068_P1S_PLA_M5_ATTACHMENT_PROTOTYPE.3mf)
with the wire groove open upward and its WIRE GROOVE SUPPORT BLOCKER retained.
The saved slice is 43m33s / 8.38 g. Re-slice for your own printer and filament.

With M5 removed, lay the three leads into the 34 × 3 mm side-open groove, keeping
DuPont housings outside its ends. The shortened 6 mm underside hook accepts three
nominal 1.3 mm leads in a staggered arrangement, loaded separately. Keep the plugs
outside the hook. Choose cable length after a dry fit with relaxed bends.

Check seating on the two support humps and actual screw engagement before
remounting M5. M2×6 is a nominal reference; the retained pad geometry overlaps the
older nominal M5 underside, so do not force seating or tighten against rocking.
Printed hook strength, wire retention and launcher clearance remain unverified.

## Firmware and controls

Use the [USB updater](https://shadohead.github.io/launchlab-mini/) in desktop Chrome or Edge. A USB data cable is required. Connect USB, then hold the side Power/Reset button until the internal green LED flashes. Close serial monitors, then connect through the page. Firmware installation begins only after clicking Connect & update/install and choosing a device. See [update instructions](UPDATER.md) for current firmware release gates; this prototype has the limits recorded below.

Update checks for the expected partition table and writes only `0x10000`. First install replaces bootloader `0x0`, partitions `0x8000`, OTA selection `0xe000`, and application `0x10000`, without erase-all. Back up factory firmware before first install if you need to restore it. A full 8 MB backup contains personal settings/data and should stay private.

Short A recalls the latest recap. Short B opens the menu: History, New session, Battery, Settings and Tournament. In menus, A opens or applies, B moves to the next choice and hold B goes back or cancels; see [the firmware guide](../firmware/LaunchLabMini/README.md). After installing, choose your sensor under Settings → Sensor profile: QRE / Standard (default) or TCRT5000. Automatic power-off uses a 3-minute default with saved 1–10 minute choices; measured pulls, buttons and interactive USB commands refresh it. A detected USB computer keeps it awake, including with no serial reader. Battery shake-wake at 80 MHz remains unverified.

Current 0.11.1 and the preserved 0.10.22/0.10.21/0.10.14/0.10.11/0.10.7/0.10.1 default to the peak of three-consecutive-turn elapsed-time
averages. Settings offers a persistent 1-turn peak alternative. In Settings,
A edits the highlighted row, B cycles its value, A applies and hold B cancels. Changing the
metric or sensor profile starts the next accepted pull in a new session. The default sleep is
3 minutes; saved 1–10 minute choices remain. Hold A on main enters tournament;
B cycles Recording Only/RPM and hold A exits. Auto-sleep restores the selected mode/view.

A fresh K150 needs **First install**, which writes bootloader, partition table,
boot_app0 and application. Update writes the application only and requires a
matching partition table. Both paths verify downloads and device MD5 without
an erase-all. First install replaces the factory app/layout; back up first.

## Troubleshooting

If no USB port appears, try a known data cable, re-enter download mode, and close apps using the serial port. A partition or boot-selection mismatch means stop and back up; do not use First install to bypass it. After an interrupted app-only update, deliberately select Repair / rollback for the intended version. An interrupted First install may also need boot/layout recovery. Follow the [recovery and stock reinstall guide](RECOVERY.md) for the correct route. A successful message requires device MD5 verification. Press Power/Reset if verified firmware does not restart automatically.

## Current qualification

**0.11.1** is the user-checked prototype revision. It adds saved themes (Classic, Mint, Amber, Violet), a personal-best effect on the recap, and USB backup and restore of history, personal bests, appearance and settings (`K` export, `R` restore). It fixes 0.11.0, which restarted about once a second after boot (a loop-task stack overflow) and was withdrawn. One firmware still serves both sensors through the saved **Sensor profile** setting (QRE / Standard with an 80-count mark floor, TCRT5000 with 60). It was installed app-only on the owner's M5StickS3 K150: no restarts in a 120 s soak, history kept, a backup and restore round trip identical, and the screen, themes and pulls confirmed. The detector, sampling, thresholds and saved history format are unchanged from 0.10.22, which keeps measuring pulls that start right after an automatic save. Battery endurance, long-session reliability, absolute RPM/angle calibration, physical browser transfer and first install/rollback, and stock recovery remain separate checks.

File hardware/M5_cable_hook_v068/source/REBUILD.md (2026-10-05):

# Rebuild the v0.68 carrier

The editable Blender file and complete manufacturing STL are included one
directory above. The STEP file contains the analytic hook only.

`carrier_before_hook.stl` is the exact pre-hook v0.65 carrier, including its
launcher attachment, side-open channel, screw seats and two support humps.
`build.py` reads the published parameters, creates the rounded hook, unions it
with that baseline, and applies the saved manufacturing pose. Its geometry does
not depend on private drawing submissions or earlier development directories.

From this directory, using Python 3.12:

```sh
python3 -m venv .venv
.venv/bin/python -m pip install -r requirements.txt
.venv/bin/python build.py --output /tmp/launchlab-v068-rebuilt
```

Choose a new output directory if that path already exists. The builder preserves
the frozen package. It emits native and print-oriented STLs plus the hook STEP.
Compare the rebuilt native STL with `../preview/01_M5_channel_two_humps_cable_hook.stl`
and the print STL with `../stl/01_M5_channel_two_humps_cable_hook.stl`.

The source dependencies record the versions used for the saved build. The source
mesh, complete carrier meshes, hook STEP and sliced 3MF retain their original
geometry. Public documentation and relative evidence paths were prepared for
this repository; private markup and local dispatch records are not included.

Rebuilding or slicing does not establish printed fit, wire retention or strength.

Rebuild verification compares mesh surfaces, bounds and volume. Coplanar
triangle subdivisions can differ without changing the carrier surface.

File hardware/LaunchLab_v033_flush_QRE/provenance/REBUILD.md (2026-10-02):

Requires the custom-beypass checkout and frozen v032 release. Choose a new output path for edits. Run build_flush_qre_v033.py, check_flush_qre_v033.py, section_flush_qre_v033.py, Blender --background --factory-startup --python scripts/render_flush_qre_v033.py, prepare_flush_qre_v033.py, check_flush_layers_v033.py, then finalize_flush_qre_v033.py. CAD/STL mm; Blender/GLB metres. One base-only local Tree Slim slice. No printer dispatch.

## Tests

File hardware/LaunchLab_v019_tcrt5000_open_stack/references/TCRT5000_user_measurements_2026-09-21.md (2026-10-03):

# TCRT5000 module: user measurements, 2026-09-21

Units: mm. These are user-reported caliper measurements of the blue TCRT5000/LM393 module pictured in IMG_7445–IMG_7448, not the subsequently discussed QRE1113 breakout. No CAD release or firmware has been changed by this record.

## Reported dimensions

| Feature | Measurement | Interpretation / uncertainty |
| --- | --- | --- |
| PCB | 31 long × 13 wide × 1 thick | Excludes components and connector extension. |
| Blue adjustment block | 7 × 7; 6 high | Height interpreted from its own PCB face to highest point, per measurement request. |
| Adjustment block longitudinal position | 12 from connector-end PCB edge | Interpreted to nearest block edge, per request; block extends to 19 from this edge. |
| Adjustment block lateral position | Approximately 0.3 from a long PCB edge | Which edge needs identification. Approximate, not an exact datum. |
| Optical head projection | 12 from its PCB face | Interpreted to outermost lens tip; black housing alone may be shorter. |
| Optical housing footprint | 10 long × 6 wide | Supplied in follow-up; orientation of the 10 mm dimension relative to PCB axes still needs confirmation. |
| Two-lens section footprint | 6 × 7 | User confirmed this describes the two-lens section; not individual lens diameters or center spacing. |
| Lens protrusion above black housing | 2.5 | User explicitly confirmed the datum is black housing to lens tip, not PCB to tip. |
| Optical head end position | 1 inset | Interpreted as housing inset from sensor-end PCB edge. Lateral position not supplied. |
| Connector extension | 6 beyond connector-end PCB edge | Bare pins; plugged-in wire housing/bend envelope not supplied. |
| Connector height | 4 from PCB surface | Side identified from photos; complete connector footprint not supplied. |
| Other solder/lead protrusions | 2 on both sides | Local protrusions; locations/footprints not supplied. Do not add 2 to already surface-referenced component heights. |

## Photo evidence and derived envelopes

The side-view photo IMG_7445 shows the blue adjustment block and the optical head on opposite PCB faces. This must be represented explicitly in the next CAD iteration.

Assuming the reported heights use the requested PCB-surface datums, the module's bounding thickness is approximately 12 + 1 + 6 = 19. This spans components at different locations; it does not imply a uniform 19 mm pocket. PCB plus bare connector pins span approximately 31 + 6 = 37 along the length. Wiring and manufacturing clearances are additional, unmeasured allowances.

## Comparison with released v0.7 reference meshes

Read directly from releases/LaunchLab_v07_simplified/preview using trimesh:

- PCB reference: 32 × 14 × 1.6, Z 13.8 to 15.4.
- Optical head reference: 10 × 5.8 × 7, Z 6.8 to 13.8; 7 projection from PCB lower face.
- Pot reference: 7 × 7 × 5, Z 8.8 to 13.8; modeled on the SAME face as the optical head, contrary to the photos.

The optical projection is 5 greater than the old assumed envelope. The adjustment block is 1 taller and on the opposite face. These reference differences are not a completed interference analysis and do not establish required enclosure height.

## Remaining geometry needed before final optical-mount design

1. Optical housing lateral position and orientation of the reported 10 × 6 footprint relative to PCB axes.
2. Identify the long PCB edge used for the approximately 0.3 adjustment-block offset.
3. Establish which way the confirmed trapezoidal opening is oriented on the mount.
4. Establish the assembled spacing between printed plate underside and launcher top; target depth datum is now confirmed below.
5. Photo with mount on launcher and relevant optical opening marked, to register the target to the preserved original-scale top connection.
6. Lens spacing/diameters if aperture clearance cannot otherwise be established, plus chosen wire connector envelope.

Preserve the original two-clip top connection scale. Do not silently substitute QRE1113 dimensions or treat any sensor as optically validated through the launcher opening. A fit coupon and real black/white signal test should precede a final revised enclosure print.

## Follow-up: outer optical opening (user-confirmed shape and depth datum)

The user subsequently confirmed the interpreted opening shape and that target depth is measured from the launcher's own top surface to its internal black/white ring. Dimensions remain user-reported and approximate, not independently verified:

- Trapezoidal opening viewed from above: 5 between the parallel edges; short edge 5; long edge 6.
- Printed plate thickness: approximately 3.
- Launcher opening: reported to have the same shape/dimensions.
- Target depth: approximately 1–2 below the launcher's own top surface, to its internal black/white ring.
- User subsequently confirmed the two-lens section is 6 × 7, with 2.5 protrusion from black housing to lens tips. This is the pair's overall footprint, not center spacing or individual lens diameters. Final optical-axis location remains unmeasured.

Raw user wording: “1. 10mm x 6 wide 2. the opening for the outer opening is 5mm tall and 5. the thickness is like 3 mm, the hole hopening on the short trapezoidal side and. 6 on the larger side and the launcher opening is the same . the depth is maybe 1-2mm. the”

The 10 × 6 housing cannot be assumed to pass through this approximately 5–6 wide opening. This does not by itself establish optical failure: the relevant quantities are both optical paths, aperture thickness, lens spacing, alignment and target gap. No release geometry has been altered using these aperture dimensions.

If the approximately 3 mm printed plate underside sits flush against the launcher top, the printed plate upper surface is approximately 4–5 mm above the target (3 + 1–2). This is NOT a measured lens-to-target gap. Any plate-to-launcher spacing and lens setback above the plate add to that distance; a lens protrusion/recessed mounting arrangement reduces it. The usable optical path through both openings still needs verification.

The reported 7 mm lens-pair span exceeds the opening's 5–6 mm transverse width. For alignment along that width this suggests partial optical obstruction, but it does not establish failure or quantify transmitted/returned light. Lens span is not emitter/receiver center spacing, and aperture orientation, lens field of view, distance and target reflection matter. Test black/white contrast through the actual launcher opening, followed by fast-pull capture, before committing a new enclosure around this sensor. Do not enlarge the launcher or change the original clip interface based on this comparison alone.

Height reconciliation: retaining the earlier interpreted 12 mm PCB-face-to-lens-tip measurement, the black housing's lens-side surface is approximately 12 - 2.5 = 9.5 mm from that PCB face. This is a derived placement dimension including the lead standoff; it is NOT the black housing's body thickness. The 2.5 mm is already included in the 12 mm total and must not be added again.

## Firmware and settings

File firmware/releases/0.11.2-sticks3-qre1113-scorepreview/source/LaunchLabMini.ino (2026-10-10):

#include <M5Unified.h>
#include <Preferences.h>
#include <memory>
#include "acquisition.h"
#include "level_indicator.h"
#include "practice_store.h"
#include "practice_ui.h"
#include "power_status.h"
#include "usb_awake.h"
#include <HWCDC.h>
#include "power_diagnostics.h"
#include <sys/time.h>
#include <esp32-hal-cpu.h>
#include "shake_wake.h"
#include "wake_ui_state.h"
#include "rpm_estimator_setting.h"
#include "display_flip_setting.h"
#include "sensor_profile_setting.h"
#include "controls_ui.h"
#include "motion_acquisition.h"
#include "motion_store.h"
#include "motion_ui.h"
#include "launch_feedback.h"
#include "appearance_store.h"
#include "best_effect_ui.h"
#include "device_backup.h"
#include "settings_effect_preview_ui.h"

// loop() runs on an 8 KB task. GCC inlines static helpers called once, and the
// frames of inlined bodies add up: 0.11.0's loop frame reached 6.9 KB and
// overflowed on the first status print. Keep heavy or rarely used helpers as
// real calls so each one uses stack only while it runs.
#define LOOP_HELPER __attribute__((noinline))
static constexpr char VERSION[] = "0.11.2-sticks3-score-preview";
#ifndef LAUNCHLAB_CPU_MHZ
#define LAUNCHLAB_CPU_MHZ 80
#endif
static_assert(LAUNCHLAB_CPU_MHZ==80 || LAUNCHLAB_CPU_MHZ==160 || LAUNCHLAB_CPU_MHZ==240,
  "CPU policy must retain the 80 MHz peripheral clock");
static constexpr uint32_t ANALOG_SAMPLE_HZ = StickS3Acquisition::SAMPLE_HZ;
#include "raw_transfer.h"
static StickS3Acquisition acquisition;
static Preferences prefs;
static StickS3Level level;
static M5Canvas screen(&M5.Display);
static PracticeHistory practice,demoPractice;
static PracticeStore practiceStore;
static Appearance::Config appearance;
static Appearance::Bests personalBests;
static AppearanceStore<Appearance::Config> appearanceStore;
static AppearanceStore<Appearance::Bests> bestStore;
static Appearance::Celebration bestEffect;
static BestEffectUI::Renderer bestEffectRenderer;
static bool effectWasMoving=false;
static SettingsEffectPreview::State settingsEffectPreview;
static PracticeUI::View historyView=PracticeUI::View::Recent;
static bool historyPage=false,demo=false,saveError=false;
static bool tournamentMode=false;
enum class TournamentView:uint8_t { RecordingOnly, Rpm };
static TournamentView tournamentView=TournamentView::RecordingOnly;
static Controls::State controls;
static Controls::Gesture gestureA,gestureB;
static bool restorePreview=false;
static uint32_t tournamentHintUntil=0;

static unsigned historyOffset=0;
static uint32_t lastSaveTry=0,saveCount=0,saveErrors=0,maxSaveUs=0,newSessionAt=0;
static constexpr uint32_t HISTORY_COALESCE_MS=10000;
static constexpr uint32_t HISTORY_SAVE_RETRY_MS=5000;
static uint32_t lastAcceptedAt=0,historyPendingSince=0;
static bool screenReady=false;
static bool diagnostics=false,extPower=false,stress=false,dirty=true;
static uint32_t lastDraw=0,lastStatus=0,lastRevision=0,maxDrawUs=0,uiStalls=0;
static uint32_t lastImuPoll=0,maxImuPollUs=0;
static StickS3Level::Reading drawnLevel;
static InactivityTimer inactivity;
static UsbHostAwake usbAwake;
static bool usbAutoOffInhibited=false;
static StickS3ShakeWake shakeWake;
static bool settingsSaveError=false;
static uint8_t brightnessPercent=40;
static bool displayFlipped=false;
static RpmEstimator::Mode rpmEstimator=RpmEstimator::DEFAULT_MODE;
static StickS3SensorProfile::Mode sensorProfile=StickS3SensorProfile::DEFAULT_MODE;
static StickS3Battery battery;
static uint32_t lastBatteryPoll=0,maxBatteryPollUs=0,lastShutdownTry=0;
static bool batteryPolled=false;
static bool powerConfigValid=false;
static uint8_t powerConfig=0;
static Preferences powerPrefs;
static PowerDiagnostics::Image powerLog;
static bool powerLogReady=false,powerLogDirty=false;
static uint32_t powerLogTick=0,lastPowerSample=0,lastPowerSaveTry=0;
struct SleepReceipt {uint32_t magic;int64_t atUs;};
RTC_DATA_ATTR static SleepReceipt sleepReceipt={};
static uint8_t pm1WakeFlags=0;
static bool pm1WakeValid=false;
static StickS3MotionAcquisition imuAcquisition;
static constexpr uint32_t MOTION_INIT_RETRY_MS=5000,MOTION_DATA_TIMEOUT_MS=250;
static uint32_t motionInitAttempts=0,lastMotionInit=0;
static bool motionInitPaired=false,motionInitSuccess=false;
static MotionStore motionStore;
static DeviceBackup::Receiver restoreRx;
static LaunchMotion::Trace latestMotion,referenceMotion,demoMotion;
static bool motionPending=false,referenceError=false,motionDemo=false;
static uint64_t motionStart=0,motionEnd=0,lastLevelSampleUs=0;
static uint32_t motionDrops=0;
static LaunchFeedback launchFeedback;
static AnalogTachometer::Phase lastPhase=AnalogTachometer::Phase::Paused;
static bool lastFault=false;
using Action=StickS3Acquisition::Action;
using Snapshot=StickS3Acquisition::Snapshot;

static bool motionSensorPaired() {
  // isEnabled only establishes driver detection. Require an actual new paired
  // read before starting the fusion owner; cached data and rest are not tests.
  M5.Imu.setCalibration(0,0,0);
  const uint32_t started=millis();
  do {
    const unsigned fresh=M5.Imu.update();
    const unsigned both=m5::IMU_Class::sensor_mask_accel|m5::IMU_Class::sensor_mask_gyro;
    if((fresh&both)==both) {
      const auto data=M5.Imu.getImuData();
      if(std::isfinite(data.accel.x) && std::isfinite(data.accel.y) && std::isfinite(data.accel.z) &&
         std::isfinite(data.gyro.x) && std::isfinite(data.gyro.y) && std::isfinite(data.gyro.z))return true;
    }
    delay(5);
  } while(uint32_t(millis()-started)<MOTION_DATA_TIMEOUT_MS);
  return false;
}

static bool startMotion() {
  if(imuAcquisition.running())return true;
  // No IMU owner exists here. Main-thread power/level calls are serialized;
  // only the missing IMU is reinitialized, not M5 or optical acquisition.
  ++motionInitAttempts;lastMotionInit=millis();
  motionInitPaired=M5.Imu.isEnabled() && motionSensorPaired();
  if(!motionInitPaired) {
    const bool detected=M5.Imu.begin(&M5.In_I2C,m5::board_t::board_M5StickS3);
    motionInitPaired=detected && motionSensorPaired();
  }
  motionInitSuccess=motionInitPaired && imuAcquisition.begin();
  Serial.printf("IMU_STARTUP attempt=%lu enabled=%d type=%d paired=%d task=%d elapsed_ms=%lu\n",
    (unsigned long)motionInitAttempts,M5.Imu.isEnabled(),int(M5.Imu.getType()),motionInitPaired,
    imuAcquisition.running(),(unsigned long)(millis()-lastMotionInit));
  return motionInitSuccess;
}

LOOP_HELPER static void retryMotion(uint32_t now,const Snapshot &s) {
  if(imuAcquisition.running() || motionPending || uint32_t(now-lastMotionInit)<MOTION_INIT_RETRY_MS ||
     (s.phase!=AnalogTachometer::Phase::Ready && s.phase!=AnalogTachometer::Phase::Paused))return;
  startMotion();dirty=true;
}

static uint8_t backlightValue(){return (unsigned(brightnessPercent)*255+50)/100;}
static bool visibleDisplayFlipped(){return controls.page==Controls::Page::Edit && controls.setting==3?bool(controls.draft):displayFlipped;}
static Appearance::Theme visibleTheme(){return controls.page==Controls::Page::Edit && controls.setting==5?Appearance::Theme(controls.draft):appearance.theme;}
static uint16_t themeAccent(){return Appearance::accent(visibleTheme());}
static void cancelSettingEdit();
static bool saveWakeNavigation(){return prefs.putUInt("wake_nav",Controls::encodeWake(controls,uint8_t(tournamentView)))==sizeof(uint32_t);}
static void syncNavigation() {
  tournamentMode=controls.page==Controls::Page::Tournament;
  historyPage=controls.page!=Controls::Page::Main && !tournamentMode;
  if(controls.page==Controls::Page::History)historyView=PracticeUI::View(controls.history);
  else if(controls.page==Controls::Page::Battery)historyView=PracticeUI::View::Battery;
  else if(controls.page==Controls::Page::Settings || controls.page==Controls::Page::Edit)historyView=PracticeUI::View::Settings;
  dirty=true;
}
static int64_t wallUs(){timeval t;gettimeofday(&t,nullptr);return int64_t(t.tv_sec)*1000000+t.tv_usec;}
static uint8_t powerFlags(){return (battery.charging?PowerDiagnostics::Charging:0)
  | (battery.chargeKnown?PowerDiagnostics::ChargeKnown:0) | (powerConfigValid && (powerConfig&0x10)?PowerDiagnostics::Led:0)
  | (extPower?PowerDiagnostics::Boost:0) | (tournamentMode?PowerDiagnostics::Tournament:0) | PowerDiagnostics::SensorRail;}
static void powerRecord(uint8_t event,uint8_t wake=0){PowerDiagnostics::append(powerLog,event,battery.voltageOk?battery.millivolts:0,
  powerFlags(),M5.Display.getBrightness(),ESP.getCpuFreqMHz(),wake);powerLogDirty=true;}
static bool savePowerLog(){
  // Bound retries after an NVS failure; repeated checkpoints keep the detector
  // in Settling and prevent subsequent pulls from being measured.
  lastPowerSaveTry=millis();
  if(!powerLogReady)return false;powerLog.checksum=PowerDiagnostics::hash(powerLog);
  const bool ok=powerPrefs.putBytes("log",&powerLog,sizeof(powerLog))==sizeof(powerLog);
  if(ok)powerLogDirty=false;return ok;
}
LOOP_HELPER static void exportPowerLog(){
  Serial.printf("POWER_LOG schema=1 boots=%lu power_button_wakes=%lu shake_wakes=%lu other_wakes=%lu sleeps=%lu awake_s=%llu known_sleep_s=%llu unknown_sleep_intervals=%lu charging_awake_s=%llu led_awake_s=%llu boost_awake_s=%llu display_awake_s=%llu records=%lu storage_ready=%d unsaved=%d current_ma=unavailable\n",
    (unsigned long)powerLog.boots,(unsigned long)powerLog.powerButtonWakes,(unsigned long)powerLog.shakeWakes,
    (unsigned long)powerLog.otherWakes,(unsigned long)powerLog.sleeps,powerLog.awakeMs/1000,powerLog.sleepMs/1000,(unsigned long)powerLog.unknownSleepIntervals,
    powerLog.chargingMs/1000,powerLog.ledMs/1000,powerLog.boostMs/1000,powerLog.displayMs/1000,
    (unsigned long)powerLog.count,powerLogReady,powerLogDirty);
  for(unsigned i=0;i<powerLog.count;++i){const auto &r=powerLog.records[(powerLog.next+PowerDiagnostics::CAPACITY-powerLog.count+i)%PowerDiagnostics::CAPACITY];
    Serial.printf("POWER_RECORD tracked_s=%llu boot=%lu event=%u battery_mv=%u flags=0x%02x backlight=%u cpu_mhz=%u wake=%u\n",
      r.elapsedSeconds,(unsigned long)r.boot,r.event,r.batteryMv,r.flags,r.brightness,r.cpuMhz,r.wake);}
}
LOOP_HELPER static void tickPowerLog(uint32_t now,const Snapshot &s){
  PowerDiagnostics::account(powerLog,now-powerLogTick,powerFlags(),M5.Display.getBrightness());powerLogTick=now;
  if(now-lastPowerSample>=60000){lastPowerSample=now;powerRecord(PowerDiagnostics::Sample);}
  if(powerLogReady && powerLogDirty && now-lastPowerSaveTry>=300000 &&
    HistoryCheckpoint::practiceIdle(now,lastAcceptedAt,HISTORY_COALESCE_MS,motionPending,launchFeedback.shown(),s.phase)
    && acquisition.request(Action::IdleCheckpointBegin,s.launches)){
    if(!savePowerLog())Serial.println("POWER_LOG_NOTICE checkpoint_failed");acquisition.request(Action::CheckpointEnd);
  }
}


static const char *tournamentViewName() {
  switch(tournamentView) {
    case TournamentView::RecordingOnly:return "recording_only";
    default:return "rpm";
  }
}
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
void loop() {
  if(imuAcquisition.lock()){M5.update();imuAcquisition.unlock();}
  pollLevel(millis());
  Snapshot s=acquisition.snapshot();
  if(M5.BtnA.isPressed() || M5.BtnB.isPressed() || M5.BtnA.wasReleased() || M5.BtnB.wasReleased())
    inactivity.touch(millis());
  const bool clickedA=gestureA.click(M5.BtnA.wasPressed(),M5.BtnA.wasHold(),M5.BtnA.wasClicked());
  const bool clickedB=gestureB.click(M5.BtnB.wasPressed(),M5.BtnB.wasHold(),M5.BtnB.wasClicked());
  if(M5.BtnA.wasHold())holdA();else if(clickedA)buttonA();
  if(M5.BtnB.wasHold())holdB();else if(clickedB)buttonB();
  pollCommands(s);
  Snapshot event;
  while(acquisition.takeEvent(event)) {
    if(event.revision!=lastRevision) {
      lastRevision=event.revision;
      Serial.printf("LAUNCH_RESULT valid=%d peak_rpm=%.1f revs=%lu amplitude=%.1f start_noise=%.1f launches=%lu end=%s t_us=%llu\n",
        event.valid,event.resultRpm,(unsigned long)event.revolutions,event.amplitude,event.startNoise,
        (unsigned long)event.launches,event.endName(),(unsigned long long)event.detectorUs);
      if(practice.accept(event.launches,event.valid,event.resultRpm,millis())) {
        prepareMotion(event);logLaunchMetrics(event);
        inactivity.touch(millis());
        Serial.printf("HISTORY_ADDED number=%lu session=%lu rpm=%.1f\n",(unsigned long)practice.recent()->number,
          (unsigned long)practice.recent()->session,practice.recent()->rpm);
      }
      dirty=true;
    }
    if(event.phase!=lastPhase || event.signalFault!=lastFault) {
      lastPhase=event.phase;lastFault=event.signalFault;dirty=true;
      Serial.printf("RPM_STATE state=%s t_us=%llu contrast=%.1f noise=%.1f\n",event.stateName(),
        (unsigned long long)event.detectorUs,event.contrast,event.noise);
    }
  }
  s=acquisition.snapshot();
  const uint32_t now=millis();
  if(s.phase==AnalogTachometer::Phase::Launch || motionDemo || tournamentMode || historyPage || diagnostics){
    if(bestEffect.badge()){bestEffect.clear();dirty=true;}else bestEffect.clear();
  }
  if(launchFeedback.tick(now)){dirty=true;motionDemo=false;Serial.printf("MAIN_FEEDBACK shown=0 reason=timeout t_ms=%lu\n",(unsigned long)now);}
  if(!launchFeedback.shown())bestEffect.clear();
  if(s.phase==AnalogTachometer::Phase::Launch)inactivity.touch(now);
  finishMotion();
  retryMotion(now,s);
  saveHistory(now,s);s=acquisition.snapshot();
  pollBattery(now,s);
  tickPowerLog(now,s);
  pollUsbAwake(now,s);
  if(restorePreview)previewSetting();
  autoPowerOff(now,s);
  pollSettingsEffectPreview(now,s);
  if(newSessionAt && now-newSessionAt>=1500){newSessionAt=0;dirty=true;}
  if(stress && now-lastDraw>=50)dirty=true;
  if((M5.BtnA.isPressed() || M5.BtnB.isPressed()) && now-lastDraw>=50)dirty=true;
  if(tournamentHintUntil && int32_t(now-tournamentHintUntil)>=0){tournamentHintUntil=0;dirty=true;}
  if(diagnostics && now-lastDraw>=500)dirty=true;
  if(historyPage && historyView==PracticeUI::View::Battery && now-lastDraw>=1000)dirty=true;
  const bool effectMoving=bestEffect.moving(now,appearance.effect);
  if((effectMoving || effectWasMoving) && now-lastDraw>=50)dirty=true;
  // One final clean frame removes the decoration; the NEW BEST label stays.
  if(dirty && (stress || s.phase!=AnalogTachometer::Phase::Launch))effectWasMoving=effectMoving;
  if(!tournamentMode && !diagnostics && !historyPage && launchFeedback.shown() && !motionPending &&
     MotionReplay::playbackNeedsFrame(motionDemo?demoMotion:latestMotion,launchFeedback.replayElapsed(now),launchFeedback.lastReplayElapsed()) && now-lastDraw>=50)dirty=true;
  if(!tournamentMode && !diagnostics && !historyPage && !launchFeedback.shown() && now-lastDraw>=100) {
    const auto tilt=StickS3Level::forDisplay(level.reading(now),visibleDisplayFlipped());
    if(tilt.state!=drawnLevel.state || (tilt.valid() &&
      (std::fabs(tilt.degrees-drawnLevel.degrees)>=0.15f ||
       std::fabs(tilt.right-drawnLevel.right)>=0.02f || std::fabs(tilt.down-drawnLevel.down)>=0.02f)))dirty=true;
  }
  // Avoid electrical display changes through an ordinary measured burst.
  // Stress mode intentionally exercises the screen even during a burst.
  if(dirty && (stress || s.phase!=AnalogTachometer::Phase::Launch)) {
    draw(s);lastDraw=millis();dirty=false;
  }
  if(Serial && now-lastStatus>=2000){lastStatus=now;status();}
  delay(1);
}

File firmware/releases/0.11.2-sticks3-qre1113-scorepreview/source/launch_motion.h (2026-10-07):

#pragma once
#include <algorithm>
#include <array>
#include <cmath>
#include <cstdint>
#include <cstring>
#include "level_indicator.h"

namespace LaunchMotion {
static constexpr float DEG=57.295779513f;
struct Quaternion {
  float w=1,x=0,y=0,z=0;
  void integrate(const float *rate,float dt) {
    const float speed=std::sqrt(rate[0]*rate[0]+rate[1]*rate[1]+rate[2]*rate[2])/DEG;
    const float angle=speed*dt/2,k=speed>1e-8f?std::sin(angle)/speed/DEG:dt/2/DEG;
    const float a=std::cos(angle),b=rate[0]*k,c=rate[1]*k,d=rate[2]*k;
    const Quaternion q{w*a-x*b-y*c-z*d,w*b+x*a+y*d-z*c,w*c-x*d+y*a+z*b,w*d+x*c-y*b+z*a};
    const float n=std::sqrt(q.w*q.w+q.x*q.x+q.y*q.y+q.z*q.z);
    w=q.w/n;x=q.x/n;y=q.y/n;z=q.z/n;
  }
  void rotate(const float *v,float *out)const {
    const float t[3]={2*(y*v[2]-z*v[1]),2*(z*v[0]-x*v[2]),2*(x*v[1]-y*v[0])};
    out[0]=v[0]+w*t[0]+y*t[2]-z*t[1];
    out[1]=v[1]+w*t[1]+z*t[0]-x*t[2];
    out[2]=v[2]+w*t[2]+x*t[1]-y*t[0];
  }
  static Quaternion blend(Quaternion a,Quaternion b,float f) {
    if(a.w*b.w+a.x*b.x+a.y*b.y+a.z*b.z<0){b.w=-b.w;b.x=-b.x;b.y=-b.y;b.z=-b.z;}
    Quaternion q{a.w+(b.w-a.w)*f,a.x+(b.x-a.x)*f,a.y+(b.y-a.y)*f,a.z+(b.z-a.z)*f};
    const float n=std::sqrt(q.w*q.w+q.x*q.x+q.y*q.y+q.z*q.z);
    q.w/=n;q.x/=n;q.y/=n;q.z/=n;return q;
  }
  static float difference(const Quaternion &a,const Quaternion &b) {
    // Normalize the dot product in double precision. Packed/float quaternions
    // can otherwise report nonzero error even when comparing an identical pose.
    const double aa=double(a.w)*a.w+double(a.x)*a.x+double(a.y)*a.y+double(a.z)*a.z;
    const double bb=double(b.w)*b.w+double(b.x)*b.x+double(b.y)*b.y+double(b.z)*b.z;
    const double dot=double(a.w)*b.w+double(a.x)*b.x+double(a.y)*b.y+double(a.z)*b.z;
    return aa>0 && bb>0?float(2*std::acos(std::min(1.0,std::fabs(dot)/std::sqrt(aa*bb)))*DEG):180;
  }
  void angles(float &roll,float &pitch,float &yaw)const {
    roll=std::atan2(2*(w*x+y*z),1-2*(x*x+y*y))*DEG;
    pitch=std::asin(std::max(-1.0f,std::min(1.0f,2*(w*y-z*x))))*DEG;
    yaw=std::atan2(2*(w*z+x*y),1-2*(y*y+z*z))*DEG;
  }
};
enum class Quality:uint8_t { Missing, Valid, Gap, Clipped, TooLong, Warming };
inline const char *name(Quality q) {
  switch(q){case Quality::Valid:return "valid";case Quality::Gap:return "Motion incomplete";
    case Quality::Clipped:return "Motion out of range";
    case Quality::TooLong:return "Pull too long";case Quality::Warming:return "Motion warming up";default:return "Motion unavailable";}
}
struct Point {
  int16_t ms=0,a[3]={},g[3]={},q[4]={16384,0,0,0};
  Quaternion rotation()const {
    Quaternion r{q[0]/16384.0f,q[1]/16384.0f,q[2]/16384.0f,q[3]/16384.0f};
    const float n=std::sqrt(r.w*r.w+r.x*r.x+r.y*r.y+r.z*r.z);
    r.w/=n;r.x/=n;r.y/=n;r.z/=n;return r;
  }
  float magnitude(bool gyro)const {
    const int16_t *v=gyro?g:a;const float scale=gyro?.1f:.001f;
    return std::sqrt(float(v[0])*v[0]+float(v[1])*v[1]+float(v[2])*v[2])*scale;
  }
  void turn(float &right,float &down)const {
    const float normal[3]={0,0,1};float v[3];rotation().rotate(normal,v);
    right=std::atan2(v[0],v[2])*DEG;down=-std::atan2(v[1],v[2])*DEG;
  }
};
struct Trace {
  static constexpr unsigned POINTS=48;
  Quality quality=Quality::Missing;
  uint32_t number=0,durationMs=0;
  float rpm=0;
  unsigned count=0;
  bool stationaryBias=false,fused=false;
  float gravity[3]={};
  StickS3Level::Reading startLevel,endLevel;
  Point points[POINTS];
  bool valid()const{return quality==Quality::Valid && count>=12 && count<=POINTS &&
    std::isfinite(rpm) && rpm>=1000 && durationMs>0 && durationMs<=2500;}
};
// q maps the sensor axes to a gravity-aligned frame; heading is arbitrary.
// Fusion runs continuously before trace reduction. g is bias-corrected deg/s.
struct Sample {uint64_t us=0;float a[3]={},g[3]={};Quaternion q;
  bool clipped=false,fused=false,settled=false,stationary=false;};
static constexpr uint64_t PRE_ROLL_US=500000,POST_ROLL_US=150000;
inline bool captureReady(uint64_t now,uint64_t end,uint64_t latestFused) {
  // Resampling can lag the newest raw poll by one grid interval. Only fused
  // coverage establishes post-roll availability; a raw timestamp cannot.
  return now>=end+POST_ROLL_US && (latestFused>=end+POST_ROLL_US || now>=end+500000);
}
inline Quaternion inverse(const Quaternion &q){return {q.w,-q.x,-q.y,-q.z};}
inline Quaternion multiply(const Quaternion &a,const Quaternion &b) {
  return {a.w*b.w-a.x*b.x-a.y*b.y-a.z*b.z,a.w*b.x+a.x*b.w+a.y*b.z-a.z*b.y,
    a.w*b.y-a.x*b.z+a.y*b.w+a.z*b.x,a.w*b.z+a.x*b.y-a.y*b.x+a.z*b.w};
}
inline Quaternion relative(const Quaternion &onset,const Quaternion &pose) {
  // Express turn in the launch's initial sensor axes. This cancels arbitrary
  // global heading and never treats constant heading offsets as launch errors.
  return multiply(inverse(onset),pose);
}
inline StickS3Level::Reading levelAt(const Quaternion &pose,const float *baseline) {
  const Quaternion inverse{pose.w,-pose.x,-pose.y,-pose.z};float gravity[3];inverse.rotate(baseline,gravity);
  StickS3Level level;level.feed(gravity[0],gravity[1],gravity[2],1);
  const auto captured=level.reading(1);return captured.valid()?captured:StickS3Level::Reading{};
}
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

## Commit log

2026-10-02 Publish LaunchLab Mini firmware, printable hardware, and USB updater
    [01_M5_stepped_platform.stl, 01_QRE_minimal_port.step, 01_QRE_minimal_port.stl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]
2026-10-02 Explain Beyblade X features and illustrate device UI and exploded hardware
2026-10-03 Publish sensor variants, hardware v0.41-v0.50 and exploded views
    [01_M5_equal_supports_platform.stl, 01_M5_level_platform.stl, 01_M5_raised_rectangle_platform.stl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]
2026-10-04 Record fresh-device first-install and readback verification
2026-10-05 Add preferred v0.68 M5 carrier with shortened cable hook
    [01_M5_channel_two_humps_cable_hook.stl, ADDED_HOOK_ONLY.stl, CABLE_HOOK_ONLY.step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]
2026-10-06 Publish user-checked 0.10.11 prototype revision
2026-10-07 Publish 0.10.14 with prompt tilt recaps and IMU recovery
2026-10-07 Verify current release metadata and avoid recursive checksum identity
2026-10-08 Publish 0.10.21 with sensor profiles, new controls and display flip
    The updater now defaults to 0.10.21 (runtime 0.10.21-sticks3-quiethint).
    It is the frozen build the user runs and reports working, and brings
    everything since 0.10.14 to the public updater:
    - A saved Sensor profile setting: QRE / Standard (80-count mark floor)
    or TCRT5000 (60-count floor), so one firmware serves both sensors.
    - Controls: A opens or applies, B advances, hold B goes back or cancels.
    - A saved 180-degree display flip with reversible preview. The live
    level, Start/End dots and 3D recap follow the flipped screen.
    - Setting editors centre the value with a "B next option" hint.
    Public source and tests are syn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
    [LaunchLabMini.ino, acquisition.h, analog_tachometer.h]
2026-10-09 Publish 0.11.1 with themes, personal-best effects and USB backup
    0.11.1 fixes the withdrawn 0.11.0, which overflowed the loop task's stack
    and restarted after boot. It adds saved themes, a personal-best recap
    effect and USB backup/restore (K export, R restore). Installed on the
    owner's M5StickS3 K150: no restarts, history kept, backup and restore
    round trip identical, screen, themes and pulls confirmed. The updater
    defaults to 0.11.1 and keeps 0.10.22 through 0.10.1 for rollback.
    [LaunchLabMini.ino, acquisition.h, analog_tachometer.h]
